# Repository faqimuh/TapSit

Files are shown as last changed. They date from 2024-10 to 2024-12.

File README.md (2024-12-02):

# TapSit
<div align="center">
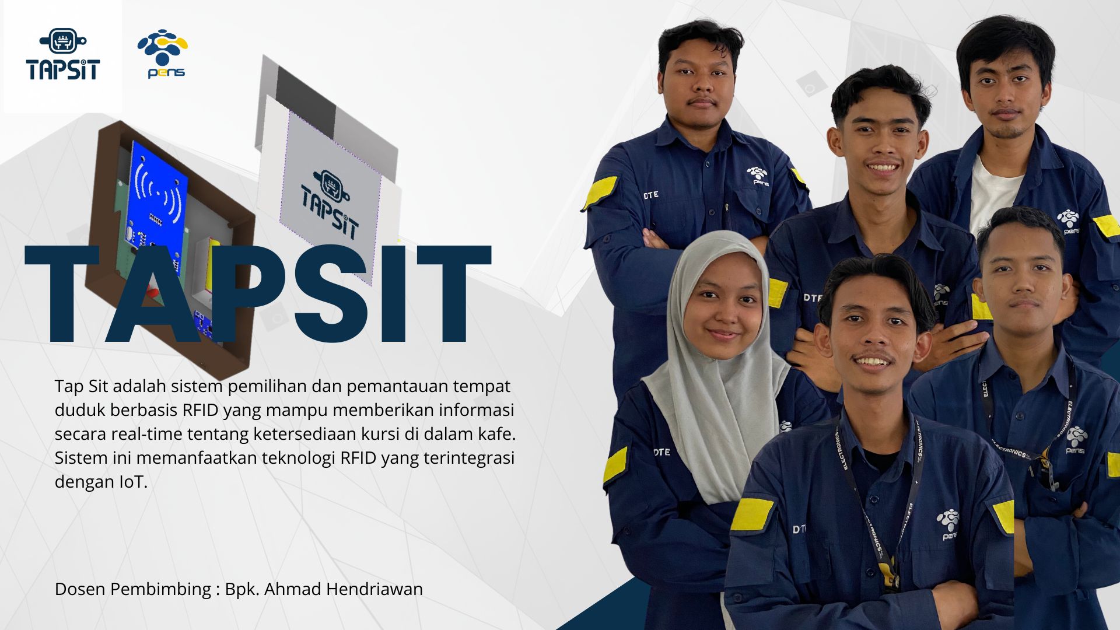
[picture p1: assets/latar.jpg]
latar
  
</div>

# Sistem Pemilihan dan Pemantauan Tempat Duduk Berbasis RFID untuk Optimalisasi Industri F&B
<div align="justify">

Proyek ini bertujuan untuk mengembangkan sistem monitoring otomatis yang memantau ketersediaan tempat duduk di kafe dan restoran, menggunakan mikrokontroler ESP32 dan teknologi RFID. Sistem ini memungkinkan pelanggan untuk memilih meja dengan mengetuk kartu RFID, yang secara instan memperbarui status meja. Data yang dikumpulkan oleh cloud server disimpan dalam database lokal dan ditampilkan di monitor kasir, memungkinkan staf untuk melihat meja yang kosong dan terisi. Dengan demikian, sistem ini meningkatkan kenyamanan pelanggan dan efisiensi operasional, serta mengurangi waktu tunggu dan kesalahan.
[Slide Presentasi TapSit](https://www.canva.com/design/DAGSyjQpQgQ/xJnBZW7nx27bsGf2SDqeiA/edit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)
</div>

`IOT DAN JARINGAN SENSOR - PROGRAM STUDI TEKNIK ELEKTRONIKA - POLITEKNIK ELEKTRONIKA NEGERI SURABAYA`

`DOSEN PENGAMPU : Akhmad Hendriawan ST, MT`
`NIP. 197501272002121003`

## Manfaat
* Mengoptimalkan Pengelolaan Tempat Duduk
* Mengurangi Waktu Tunggu Pelanggan
* Meningkatkan Efisiensi Operasional
* Meningkatkan Kepuasan Pelanggan
* Mengurangi Kesalahan dalam Pengelolaan Tempat Duduk
* Memudahkan Rotasi Pelanggan
* Peningkatan Citra Modern dan Teknologi

## Keunggulan
* Pemantauan Real-time
* Otomatisasi Berbasis IoT
* Modular dan Skalabel
* Kompatibilitas dengan Infrastruktur Jaringan Lokal
* Visualisasi yang Jelas untuk Staf
* Penggunaan Teknologi RFID yang Cepat dan Aman
* Fleksibilitas Protokol Komunikasi

## Development Plan
### Tahun 1
* Monitoring kursi kosong dalam waktu nyata.
* Akses ke platform pemantauan tempat duduk berbasis cloud
* Notifikasi kursi kosong dalam waktu nyata.
* Laporan penggunaan kursi bulanan.
* Dukungan perangkat keras untuk 10 unit pembaca RFID.
### Tahun 2
* Pemantauan multi-lokasi (hingga 3 cabang).
* Laporan penggunaan kursi mingguan dan bulanan.
* Integrasi dengan aplikasi reservasi pihak ketiga.
* Dukungan perangkat keras untuk 30 unit pembaca RFID.
### Tahun 3
* Analitik lanjutan dan laporan custom sesuai permintaan.
* Dukungan pemantauan untuk hingga 10 lokasi.
* Sistem pemesanan kursi langsung untuk pelanggan melalui aplikasi mobile.
* Dukungan perangkat keras untuk 50 unit pembaca RFID.

## Teammates
<div align="center">

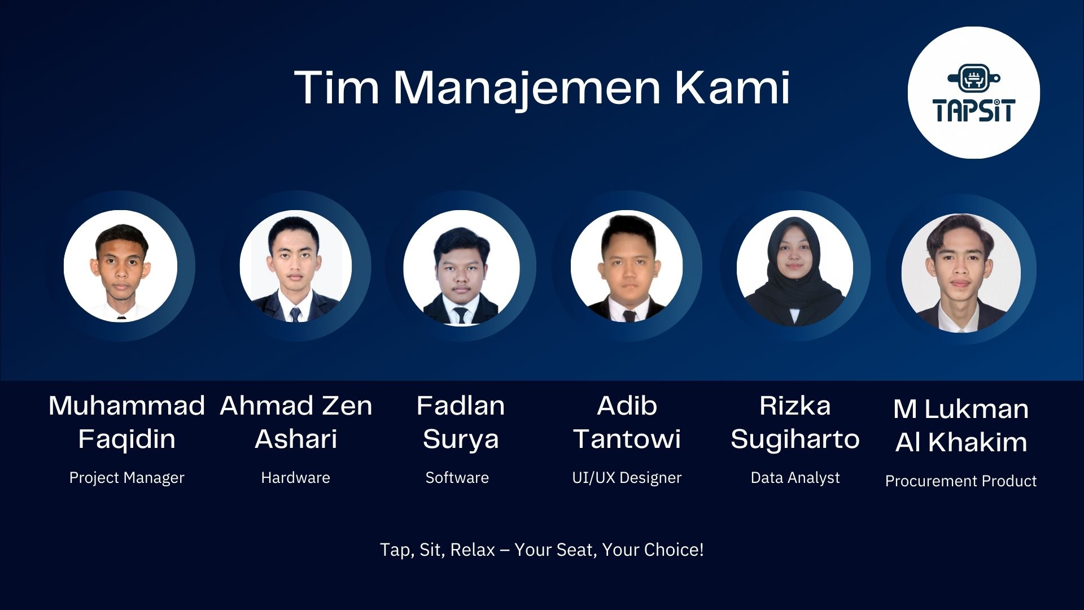
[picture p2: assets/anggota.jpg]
  

| No. | Nama | NRP | Pembagian Tugas | GitHub |
| :--:| :---:| :---:| :---:| :---: |
| 1 | Muhammad Faqidin | 2122600013 | Project Manager, Publikasi melalui Github | [GitHub](https://github.com/faqimuh) |
| 2 | Ahmad Zen Ashari | 2122600009 | Hardware, Desain Skematik dan Hardware, Publikasi melalui Github| [GitHub](https://github.com/ahmadzenashari) |
| 3 | Fadlan Surya | 2122600024 | Software, Mengatur Koneksi Hardware ke Broker, Publikasi melalui Github | [GitHub](https://github.com/fadlansuryanindita) |
| 4 | Adib Tantowi | 2122600001 | UI/UX Designer, Membuat tampilan Web Server, Publikasi melalui Github | [GitHub](https://github.com/AdibTantowi) |
| 5 | Rizka Sugiharto | 2122600008 | Data Analyst, Mengambil data dari Broker ke DataBase, Publikasi melalui Github | [GitHub](https://github.com/Rizka-sgh) |
| 6 | M Lukman Al Khakim  | 2122600010 | Procurement Product, Proses Perakitan dan Soldering, Publikasi melalui Github | [GitHub](https://github.com/2122600010-M-Lukman-Alkhakim) |

</div>

# Daftar Isi
- [Desain Produk](#Desain-Produk)
- [Diagram Arsitektur Sistem](#Diagram-Arsitektur-Sistem)
- [Hardware](#Hardware)
    * [Rangkaian Skematik](#Rangkaian-Skematik)
    * [Pin I/O](#Pinout)
    * [Layout PCB](#Layout-PCB)
- [Software](#Software)
  * [Aktifasi SSL/TLS di Broker HiveMQ CLoud](MQTT/MQTT.md)
  * [Membuat Cloud di AWS Console (EC2)](Cloud/VPS.md)
  * [Koneksi Broker dengan Database Menggunakan Node-Red](Database/progres.md)
- [Rincian Biaya](#Rincian-Biaya)

# Desain Produk

<div align="center">

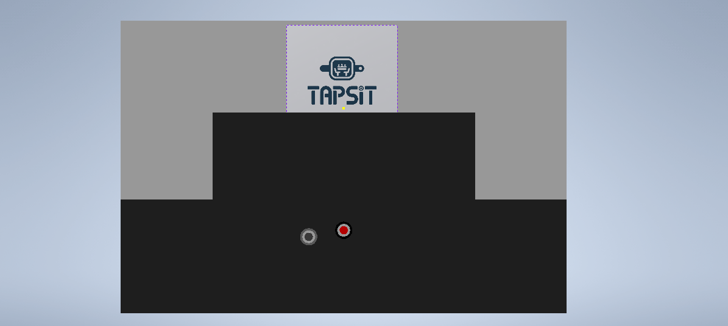
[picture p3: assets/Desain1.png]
Tampilan Produk 0
 
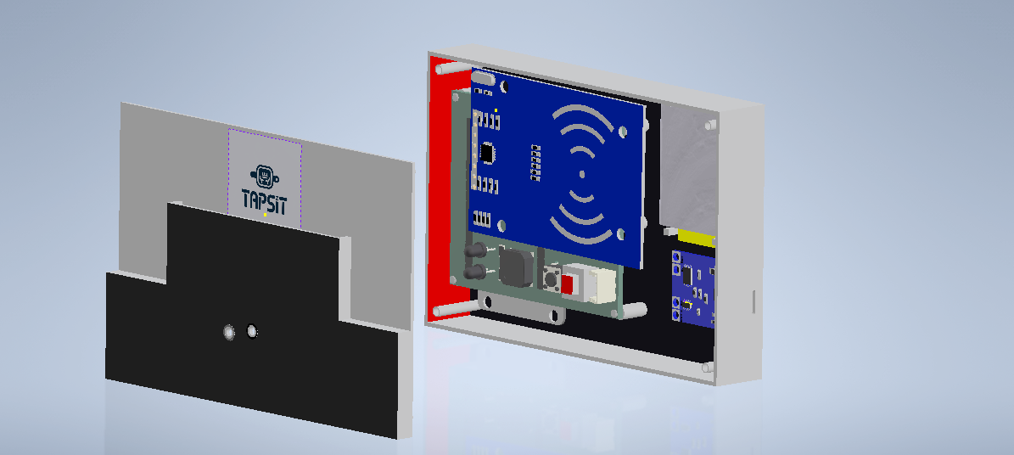
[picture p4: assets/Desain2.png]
Tampilan Produk 1
 
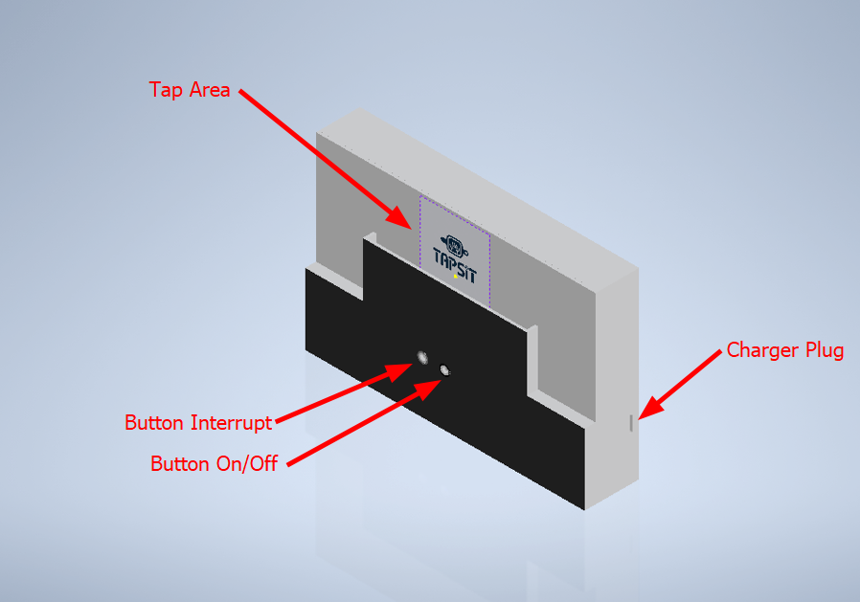
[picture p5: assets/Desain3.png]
Tampilan Produk 2
 

[def0]: /assets/Desain1.png
[def1]: /assets/Desain2.png
[def2]: /assets/Desain3.png
[Download File 3D](https://www.thingiverse.com/thing:6816870) <br>
[File 3D](https://github.com/faqimuh/TapSit/tree/main/Hardware%20Development/Desain3D)
</div>

## Uploud Casing di thingivers
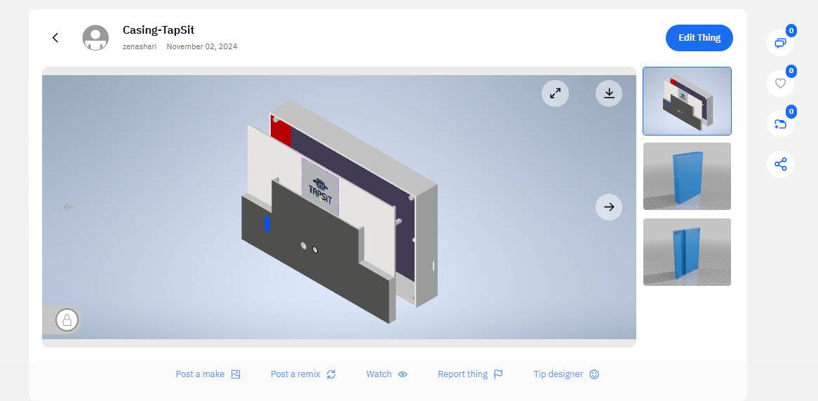
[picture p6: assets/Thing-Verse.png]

<div align="center">

https://www.thingiverse.com/thing:6816870
</div>

## Diagram Block
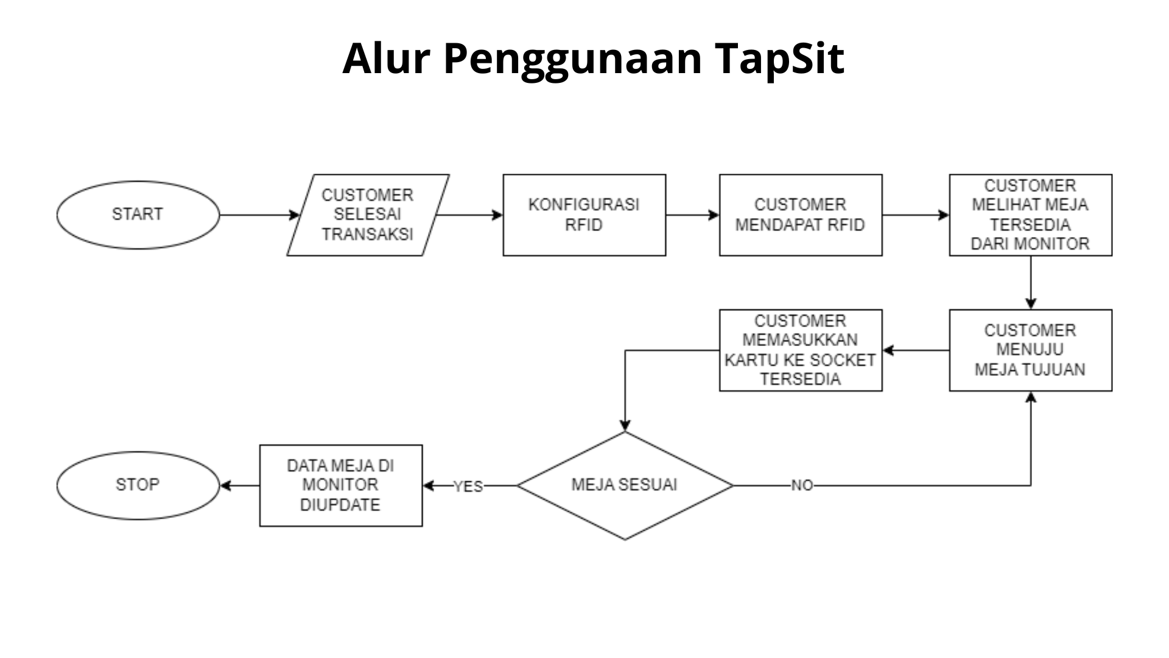
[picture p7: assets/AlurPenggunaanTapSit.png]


# Diagram Arsitektur Sistem

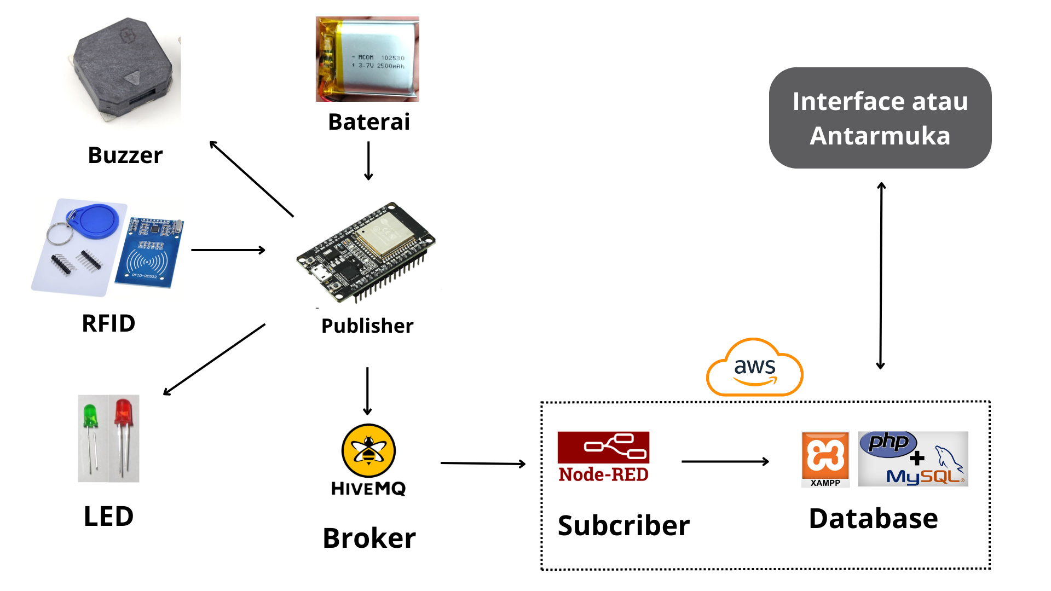
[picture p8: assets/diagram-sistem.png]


# Hardware
## Rangkaian Skematik
<div align = center>
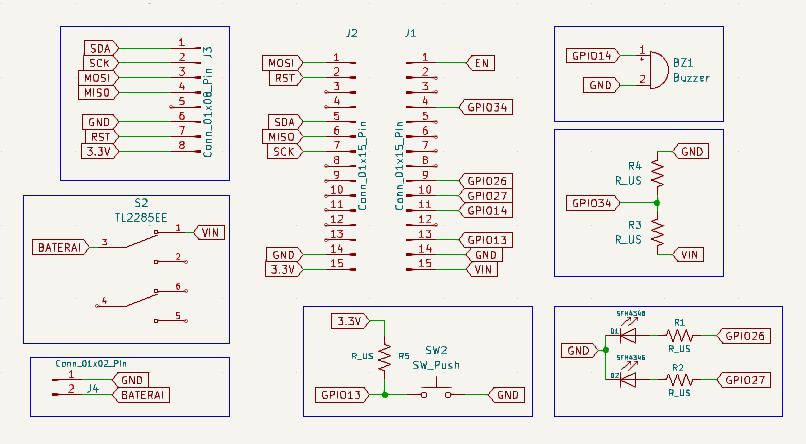
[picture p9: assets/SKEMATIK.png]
Skematik

</div>

 ## Layout PCB
 <div align = center>
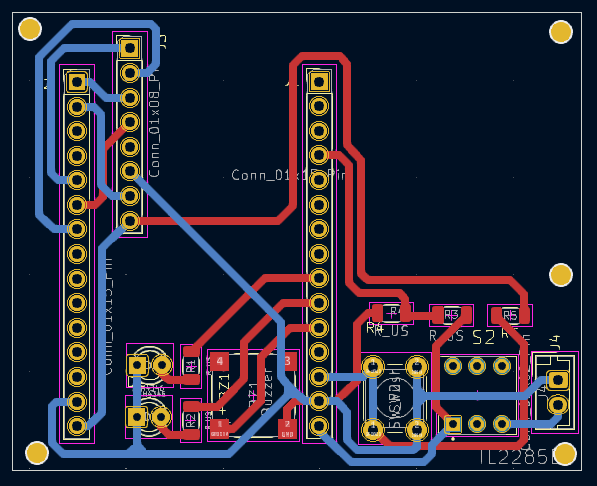
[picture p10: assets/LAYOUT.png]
Layout
  

<p> Menggunakan PCB 2 Layer </p>
<a href="https://github.com/faqimuh/TapSit/tree/main/Hardware%20Development/LayoutPCB">FILE PCB</a>
</div>

  ## Pinout yang Dipakai

Pin GPIO34 | untuk data input baterai<br>
Pin GPIO26 | untuk indikator LED<br>
Pin GPIO27 | untuk indikator LED<br>
Pin GPIO13 | untuk input interrupt<br>
Pin GPIO14 | untuk output buzzer<br>
Pin MISO   | untuk RFID <br>
Pin MOSI   | untuk RFID<br>
Pin SCK    | untuk RFID<br>
Pin SDA    | untuk RFID<br>
Pin RST    | untuk RFID<br>
Pin 3,3V   | untuk input tegangan<br>
Pin GND    | untuk ground<br>

# Software
Selamat datang di proyek ini. Berikut adalah beberapa panduan yang mungkin Anda butuhkan:
- [Aktifasi SSL/TLS di Broker HiveMQ CLoud](MQTT/MQTT.md)
- [Membuat Cloud di AWS Console (EC2)](Cloud/VPS.md)
- [Koneksi Broker dengan Database Menggunakan Node-Red](Database/progres.md)

# Rincian Biaya

| No  | Item | Jumlah | Harga | Total |Link|
|-----|---|---|---|---|-----|
| 1 | ESP32 Devkitc 32D | 1 | 66.900  | 66.900  |[Buy](https://s.shopee.co.id/g7zNegvfe) |
| 2 | Buzzer SMD 8530 3V | 1 | 4.000 | 4.000 |[Buy](https://www.tokopedia.com/marnov/buzzer-smd-8530-3v-16r-8-5-3mm-piezo-mini-aktif-pasif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) |
| 3 | LED SMD 1206 | 2 | 140 | 280 |[Buy](https://tokopedia.link/4pipX6fPrNb)|
| 4 | RFID MRFC 522 | 1 | 14.000  | 14.000  |[Buy](https://s.shopee.co.id/sIaWPa9R) |
| 5 | Resistor SMD 1206 | 3 | 150 | 450 |[Buy](https://tokopedia.link/CMivhgmPrNb) |
| 6 | Etching Papan PCB | 1 | 8.000 | 8.000 | |
| 7 | 3D print casing | 1 | 20.000  | 20.000  | |
| 8 | TP4056 1A 5V Lithium | 1 | 4.000 | 4.000 |[Buy](https://www.tokopedia.com/isee/tp4056-1a-5v-lithium-lipo-18650-battery-charging-usb-type-c-proteksi) |
| 9 | Lithium 2500mah 3.7V | 1 | 37.000  | 37.000  |[Buy](https://id.shp.ee/LSUCxvz) |
| | | | **TOTAL** | 154.630 |

# Tampilan UI/UX
<div align="center">
  <h3><span style="color:#0078D7;">Tampilan Index</span></h3>
   <p><i>Menampilkan informasi ketersediaan meja secara real-time, membantu pengguna mengetahui meja yang kosong atau terisi.</i></p>
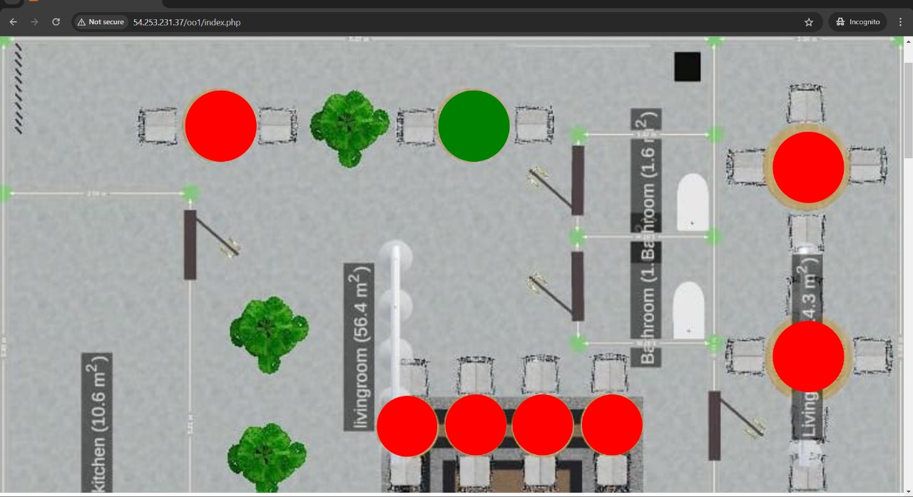
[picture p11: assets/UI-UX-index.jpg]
Index
  
</div>

<div align="center">
  <h3>Tampilan Login </h3>
  <p><i>Halaman login untuk mengamankan akses ke web admin, dirancang khusus agar hanya karyawan atau pemilik yang dapat masuk .</i></p>
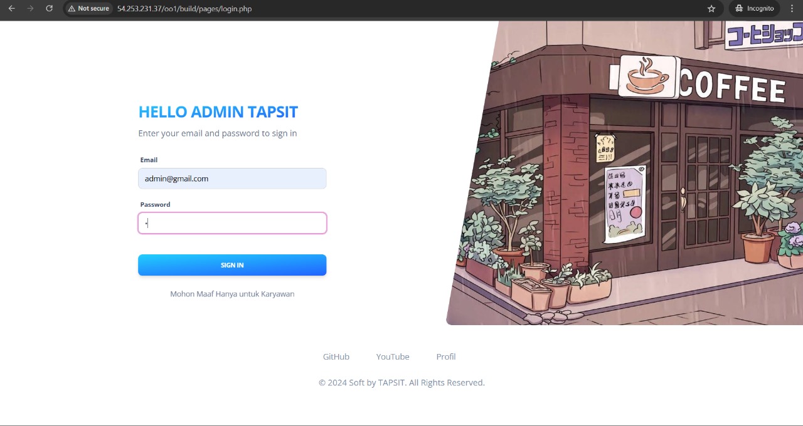
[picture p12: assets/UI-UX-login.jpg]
Login
  
</div>

<div align="center">
  <h3> Tampilan Admin </h3>
  <p><i>
    Tampilan ini dirancang khusus untuk karyawan atau pemilik yang memiliki akses ke halaman admin. Melalui halaman ini, mereka dapat memantau kondisi meja secara real-time, termasuk informasi apakah meja kosong atau terisi, serta melihat status RFID di setiap meja. Selain itu, halaman ini terdapat pengecekan tingkat baterai alat RFID, yang dikategorikan dalam tiga kondisi: aman, hampir habis, atau habis, guna memastikan perangkat berfungsi dengan optimal. Admin juga memiliki kemampuan untuk mengganti password login sebagai langkah menjaga keamanan akses sistem.
  </i></p>
  </i></p>
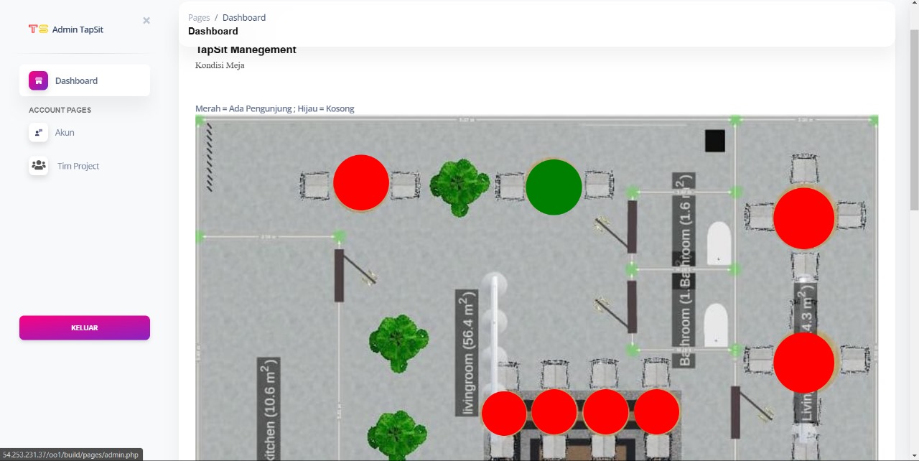
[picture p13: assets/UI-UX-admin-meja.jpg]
Admin - Kondisi Meja
  
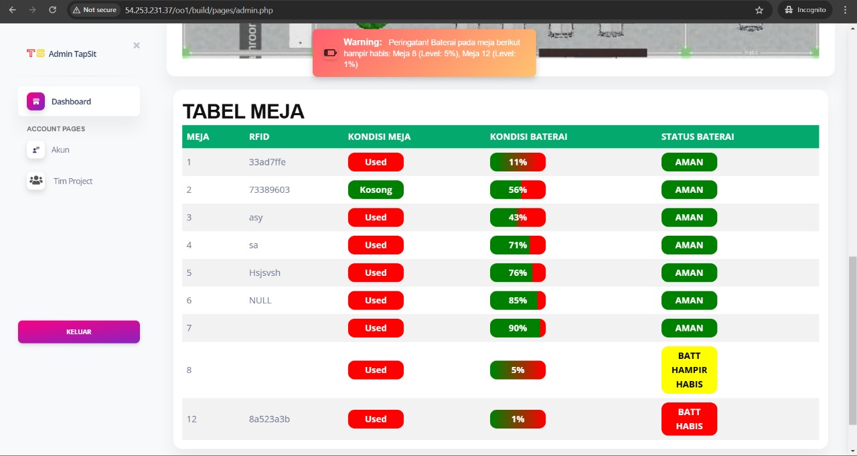
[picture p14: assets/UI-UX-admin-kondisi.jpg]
Admin - Kondisi Alat
  
  <a href="https://github.com/faqimuh/TapSit/tree/main/Interface%20UI/UX">FILE UI-UX</a>
</div>

# Cara Penggunaan 

https://github.com/user-attachments/assets/884f3dd7-7e4f-4ce1-bf2d-9252606a5dd6

1. Pastikan perangkat dalam kondisi menyala dan telah berhasil terhubung dengan jaringan Wi-Fi untuk memastikan kelancaran proses komunikasi data.
2. Pada tampilan web server, sistem akan menampilkan status setiap meja; meja yang belum terisi akan ditandai dengan warna hijau, sementara meja yang telah terisi akan ditandai dengan warna merah, memungkinkan pemantauan kondisi secara visual.
3. Tempelkan kartu RFID yang sudah terdaftar pada perangkat untuk mengaktifkan proses pengenalan identitas melalui sensor.
4. Data dari kartu RFID yang ditempelkan akan secara otomatis dikirim dan disimpan dalam database untuk tujuan pencatatan dan pemantauan.
5. Pada perangkat atau meja yang sama, sistem database hanya akan memperbarui informasi terkait kondisi terakhir RFID serta status pemantauan baterai untuk efisiensi penyimpanan dan pemrosesan data.
6. Setelah kartu RFID berhasil ditempelkan pada perangkat, tampilan pada web server akan secara otomatis diperbarui, menunjukkan bahwa meja tersebut telah terisi, berkat registrasi yang telah terjadi melalui perangkat.

Untuk memberikan gambaran yang lebih jelas, video ini akan menunjukkan seluruh proses, mulai dari pengaktifan hingga penggunaan alat dalam berbagai kondisi, sehingga Anda bisa memahami manfaat dan efisiensi alat kami yang dapat diakses pada link [VIDIO IKLAN](https://youtu.be/MPJk97POcxs?si=4I_-UE-o9XQQt0bo)

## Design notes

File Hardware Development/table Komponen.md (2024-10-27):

# Perbandingan Komponen

| No  | Komponen | Alternatif | Fitur Utama | Keunggulan | Alasan Pemilihan |
|-----|---|---|---|---|---|
| 1 | ESP32 Devkitc 32D | ESP8266 | Wi-Fi, Bluetooth | Konsumsi daya rendah, fitur lengkap | **ESP32 dipilih** karena memiliki fitur lebih lengkap (Wi-Fi, Bluetooth, dan GPIO 34 pin) serta konsumsi daya lebih rendah. Sementara itu, ESP8266 hanya mendukung Wi-Fi dengan GPIO lebih sedikit. |
| 2 | Buzzer SMD 8530 3V | Piezo Speaker | Indikasi suara | Biaya murah, mudah diimplementasi | **Buzzer** dipilih karena lebih murah dan cukup untuk memberikan umpan balik suara sederhana. Piezo speaker lebih mahal dan tidak diperlukan untuk fungsi dasar ini. |
| 3 | LED SMD 1206 | LED 5mm | Efisiensi energi, ukuran kecil | Konsumsi daya rendah | **LED SMD** dipilih karena ukurannya lebih kecil dan lebih efisien daripada LED 5mm, cocok untuk aplikasi hemat energi. |
| 4 | RFID MRFC 522 | PN532 RFID | Komunikasi RFID 13.56 MHz | Biaya rendah, ukuran kecil | **MRFC 522** dipilih karena ekonomis dan cukup untuk aplikasi sederhana. PN532 memiliki fitur lebih banyak tetapi tidak dibutuhkan dan harganya lebih tinggi. |
| 5 | Resistor SMD 1206 | Resistor Through Hole | Komponen pasif | Ukuran kecil, stabilitas tinggi | **Resistor SMD** dipilih karena lebih kecil dan sesuai untuk produksi PCB, menghemat ruang dibanding resistor through-hole yang lebih besar dan kurang efisien. |
| 6 | Etching Papan PCB | Veroboard | Desain rangkaian tetap | Struktur stabil | **Papan PCB** dipilih untuk instalasi permanen yang rapi dan stabil, sedangkan Veroboard lebih cocok untuk prototyping. |
| 7 | 3D Print Casing | Kotak Plastik | Penyimpanan komponen elektronik | Melindungi dari debu dan air  | **Box hasil 3D printing** dipilih karena memberikan perlindungan lebih baik terhadap debu dan air dibandingkan kotak plastik biasa. |
| 8 | Modul Battery TP4056 1A 5V Lithium | NiMH Rechargeable | Rechargeable, kapasitas tinggi | Ringan, efisiensi daya tinggi | **Modul Battery TP4056** dipilih karena lebih efisien dan ringan dibandingkan NiMH, yang lebih berat dan kurang efisien untuk aplikasi dengan pengisian ulang berulang. |
| 9 | Lithium 2500mAh 3.7V | NiMH Rechargeable | Kapasitas tinggi, ringan | Daya tahan lama, efisiensi tinggi | **Baterai Lithium 2500mAh 3.7V** dipilih karena bobotnya ringan, kapasitas tinggi, dan efisiensi lebih baik. Dibandingkan NiMH, Lithium memiliki kecepatan pengisian lebih cepat, self-discharge rendah, dan lebih sesuai untuk aplikasi jangka panjang. |

## Komponen
### 1. Resistor
Pembagi Tegangan:<br>
𝑉𝑜𝑢𝑡 = 𝑉𝑖𝑛 × 𝑅2 / (𝑅1 + 𝑅2)<br>
    Diketahui:<br>
                𝑉𝑖𝑛 = 12V<br>
                𝑉𝑜𝑢𝑡 = 3V<br>
                𝑅1 = 10KΩ<br>
𝑅2 = (𝑉𝑜𝑢𝑡 × 𝑅1) / (𝑉𝑖𝑛 − 𝑉𝑜𝑢𝑡)<br>
𝑅2 = (3V × 10KΩ) / (12V − 3V)<br>
𝑅2 = 3.33KΩ<br>
Hasil: Untuk mendapatkan tegangan output 3V dari sumber 12V, dengan R1 = 10KΩ, diperlukan R2 = 3.33KΩ.
<br>
Note :<br>
Untuk menurunkan Tegangan, Pembagi tegangan memungkinkan penurunan tegangan dari sumber yang lebih tinggi ke nilai yang lebih rendah, sesuai dengan kebutuhan komponen di rangkaian.<br>
<br>
### 2. Battery
Diketahui:<br>
Arus max beban = 200mA<br>
Waktu pemakaian = 12 jam<br>
Kapasitas Baterai = Arus Beban × Waktu Pemakaian<br>
Kapasitas = 200 mA × 12 jam = 2400 mAh<br>
Waktu Pengisian Baterai:<br>
Waktu Pengisian = Kapasitas Baterai / Arus Pengisian<br>
Waktu = 2500 mAh / 1000 mA × 1/0.8 = 3.125 jam<br>
Perkiraan Lama Pemakaian:<br>
Lama Pemakaian = Kapasitas Baterai / Arus Beban<br>
Lama = 2500 mAh / 200 mA = 12.5 jam<br>
Note :<br>
Dengan Menggunakan baterai berkapasitas besar seperti 2500mAh atau 3000mAh juga dapat meningkatkan efisiensi pengisian. Modul pengisian seperti TP4056 akan bekerja lebih optimal ketika dipasangkan dengan baterai berkapasitas lebih besar karena pengisian akan berlangsung lebih lama pada arus yang lebih tinggi, mengurangi kerugian daya akibat pengisian berulang kali.

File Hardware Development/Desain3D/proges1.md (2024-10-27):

<div align="center">
  <h1>Desain 3D Produk</h1>
  <h2>Tampilan 3D PCB</h2>
  
  <!-- Gambar PCB -->
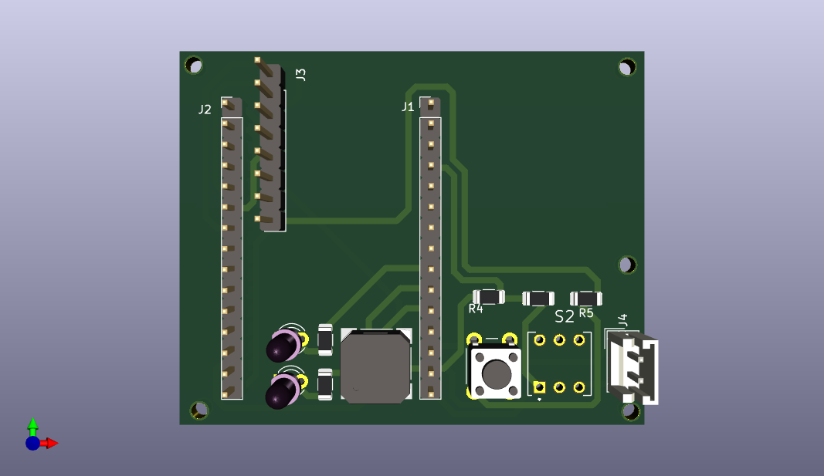
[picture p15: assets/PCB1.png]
Tampilan Produk 1
    
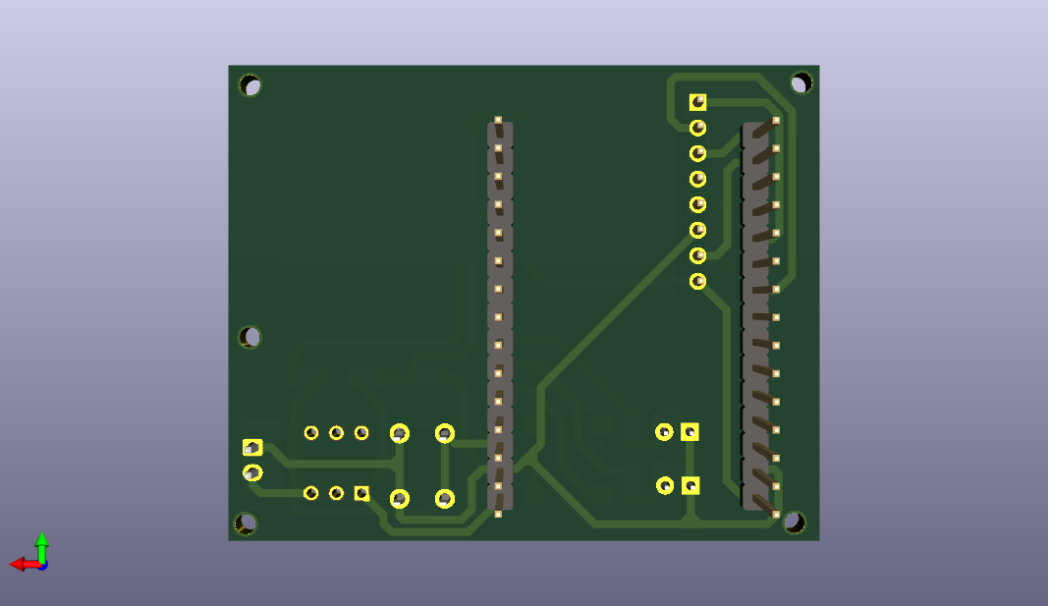
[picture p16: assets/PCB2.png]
Tampilan Produk 2
   

  <!-- Gambar yang menjadi tautan ke video -->
 <h2> Tampilan Produk </h2>
<video controls src="../../assets/produk.mp4" title="Title"></video>

 <h3>Tampak Depan</h3>

 Tampilan Produk 3

  <h3>Tampak Samping</h3>
 
 Tampilan Produk 4

  <h3> Keterangan Bagian</h3>
 
 Tampilan Produk 5

</div>

[def1]: /assets/PCB1.png
[def2]: /assets/PCB2.png
[def3]: /assets/Desain1.png
[def4]: /assets/Desain2.png
[def5]: /assets/Desain3.png

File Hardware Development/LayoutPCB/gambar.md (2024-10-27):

<div align="center">
  <h1> Layout PCB </h1>
  
  Tampilan Produk 1 
</div>

[def1]: /assets/LAYOUT.png

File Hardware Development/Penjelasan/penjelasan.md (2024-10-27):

<div style="background-color: #2e2e2e; padding: 10px; border-radius: 5px; color: white;">
  <h1>WORKSHOP MIKROKONTROLLER - PROGRAM STUDI TEKNIK ELEKTRONIKA - POLITEKNIK ELEKTRONIKA NEGERI SURABAYA</h1>
  <p>DOSEN PENGAMPU : Akhmad Hendriawan ST, MT <br/> NIP. 197501272002121003 <br/>Dibuat Oleh : Ahmad Zen Ashari<br/> NRP : 2122600009</p>
</div>

<div align = center>
 <h2>Penjelasan Skematik</h2>

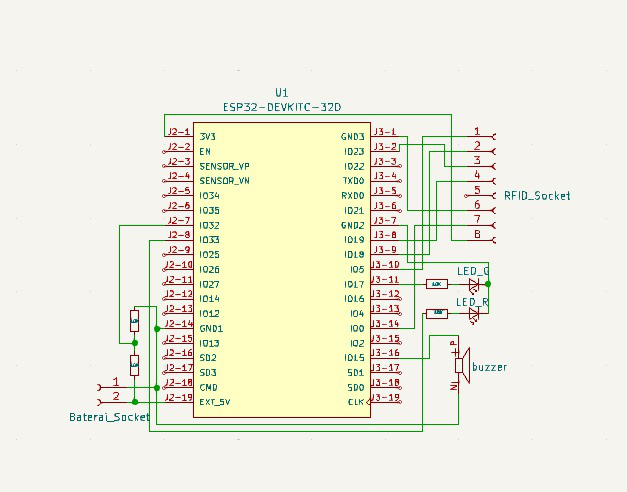
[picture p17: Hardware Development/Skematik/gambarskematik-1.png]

</div>

<div align=center>
<h3> Daftar pin yang digunakan </h3>
<!-- Tabel dengan CSS di file Markdown -->
<div class="table-container">
    <table>
        <thead>
            <tr>
                <th>No</th>
                <th>Pin GPIO Ke- </th>
                <th>Alasan</th>
                <th>Fungsi</th>
            </tr>
        </thead>
        <tbody>
            <tr>
                <td>1</td>
                <td>32</td>
                <td>Aman untuk I/O</td>
                <td>Input info daya baterai</td>
            </tr>
            <tr>
                <td>2</td>
                <td>15</td>
                <td>Aman untuk I/O</td>
                <td>Output ke buzzer</td>
            </tr>
            <tr>
                <td>3</td>
                <td>33</td>
                <td>Aman untuk I/O</td>
                <td>Output ke LED_G</td>
            </tr>
            <tr>
                <td>4</td>
                <td>17</td>
                <td>Aman untuk I/O</td>
                <td>Output ke LED_R</td>
            </tr>
         </tbody>
    </table>

<p>Untuk file skematik, dapat diunduh <a href="https://drive.google.com/file/d/1diomlFyTaUs_eFDkaGRLsYESl7vDo8c1/view?usp=sharing">di sini</a>.</p>

<div align = center>
 <h2>Penjelasan Layout</h2>

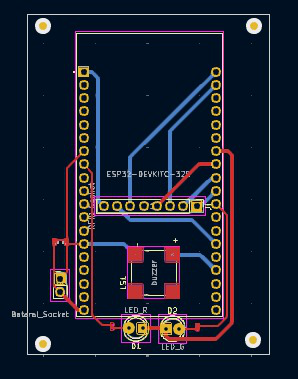
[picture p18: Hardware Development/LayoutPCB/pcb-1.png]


</div>

<p> Menggunakan PCB 2 Layer <br>Ukuran jalur 0,75mm dan 0,3mm</p>

<p>Untuk file PCB, dapat diunduh <a href="https://drive.google.com/file/d/1fTUtGnzqFyHy10sOkZaSZF4weKkYOswV/view?usp=sharing">di sini</a>.</p>

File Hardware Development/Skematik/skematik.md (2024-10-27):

<div align="center">
  <h1> Layout PCB </h1>
  
  Tampilan Produk 1 

</div>

[def1]: /assets/SKEMATIK.png

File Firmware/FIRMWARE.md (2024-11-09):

# TAPSIT FIRMWARE
<div align="justify">
Firmware diprogram dengan menggunakan software PLATFORM IO pada Visual Studio Code. Program menggunakan framework milik arduino dengan tujuan mempermudah penggunaan library pada sistem.
</div>

## LIBRARY

Library yang kami gunakan untuk memprogram firware dari system kami meliputi sebagai berikut.  

#### 1. <WiFi.h> dan <WiFiManager.h>
<div align="justify">
        Library `wifi`  digunakan untuk menghubungkan system hardware dengan koneksi internet dengan protokol wifi atan wlan (wireless lan). Untuk melakukan konfigurasi tersebut, digunakanlah  library `wifi manager`. Salah satu Kelebihan dari library wifi manager ada pada fitur penyimpanan konfigurasi wifi yang telah disetting. Library `wifi manager` juga kami setting secara `advance` untuk memberikan input parameter tambahan yang dicustom untuk memberikan suatu variable untuk device tersebut.  Pada library `wifi manager` yang disetting advance juga dapat menambahkan button untuk melakukan reset konfigurasi dari koneksi wifi dan juga dapat membuat suatu algoritma timeout ketika wifi tidak dapat tersambung.

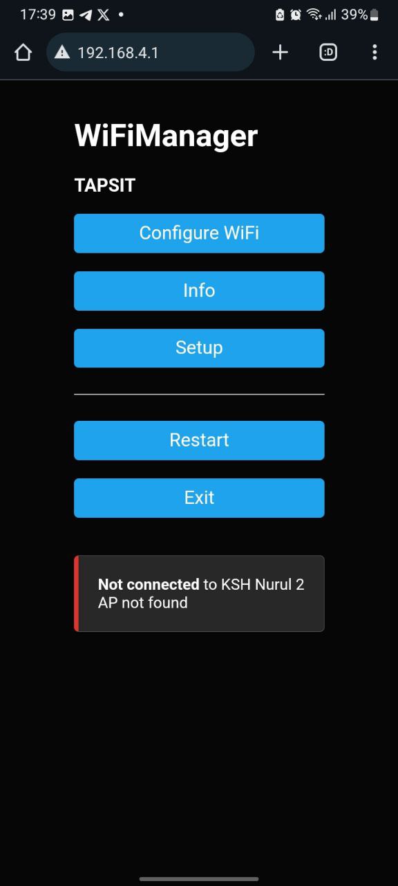
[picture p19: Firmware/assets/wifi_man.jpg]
Layout


</div>

#### 2. <PubSubClient.h>
<div align="justify">
        Library `PubSubClient` adalah library Arduino yang digunakan untuk mengimplementasikan komunikasi **Message Queue Telemetry Transport* (MQTT) pada microcontroller seperti ESP32 atau ESP8266. `MQTT` merupakan protokol komunikasi yang ringan dan banyak digunakan dalam aplikasi *Internet of Things* (IoT) untuk mengirim dan menerima data antara perangkat dan *server* (broker) melalui jaringan internet.
</div>

#### 3. <Preferences.h>
<div align="justify">
        Library `Preferences` di ESP32 memungkinkan penyimpanan data secara non-volatile, sehingga data tetap tersimpan meskipun perangkat dimatikan atau di-restart. Dengan menggunakan `Preferences`, kamu dapat menyimpan berbagai jenis data, seperti string, integer, dan boolean, dengan cara yang mudah dan efisien. Proses dimulai dengan menginisialisasi objek `Preferences` di dalam fungsi `setup()`, kemudian menyimpan data seperti nomor meja atau identitas hardware menggunakan metode `putString()`, `putInt()`, atau metode lainnya sesuai tipe data yang diinginkan. Untuk mengambil data yang telah disimpan, cukup gunakan metode `getString()` atau `getInt()` dengan kunci yang sama yang digunakan saat menyimpan. Selain itu, library ini juga menyediakan fungsi untuk menghapus data yang disimpan jika diperlukan. Semua data yang disimpan berada dalam flash memory ESP32, sehingga tetap dapat diakses setelah perangkat dimatikan. Dalam aplikasi kamu, library `Preferences` digunakan untuk menyimpan data nomor meja atau identitas hardware ESP32 yang didapat dari custom parameter WiFi Manager Advance, memastikan bahwa informasi ini selalu tersedia bahkan setelah perangkat di-restart. Dengan demikian, library `Preferences` sangat cocok digunakan untuk menyimpan informasi penting yang perlu diakses kembali setelah restart, seperti data konfigurasi atau identitas unik dalam aplikasi IoT.
</div>

#### 4. <SPI.h> dan <MFRC522.h>
<div align="justify">
      Library `<SPI.h>` dan `<MFRC522.h>` kami gunakan secara bersamaan untuk mengoperasikan RFID reader MFRC522 dengan mikrokontroler seperti Arduino atau ESP32. Library `<SPI.h>` menyediakan antarmuka untuk komunikasi SPI (Serial Peripheral Interface), yang merupakan protokol yang diperlukan untuk berkomunikasi dengan perangkat seperti MFRC522. Di sisi lain, library `<MFRC522.h>` menyediakan fungsi khusus untuk mengatur dan mengelola operasi RFID, termasuk membaca dan menulis data pada kartu RFID. Penggunaannya dimulai dengan menginisialisasi objek MFRC522 dan mengatur koneksi SPI di dalam fungsi `setup()`. Setelah itu, kami dapat menggunakan berbagai fungsi yang disediakan oleh library ini untuk mendeteksi kartu RFID, membaca informasi dari kartu, atau melakukan operasi lain yang berkaitan dengan RFID. Kombinasi kedua library ini memungkinkan kami untuk mengembangkan aplikasi berbasis RFID yang efektif, seperti sistem akses kontrol atau manajemen inventaris, dengan cara yang sederhana dan intuitif.
</div>
        
#### 5. "esp32-hal-timer.h"
<div align="justify">
        File header `esp32-hal-timer.h` dalam framework Arduino untuk ESP32 digunakan untuk mengelola timer dengan efisien. File ini menyediakan fungsi untuk menginisialisasi dan mengonfigurasi timer dalam mode one-shot dan periodic, serta memungkinkan pengaturan prescaler untuk menentukan kecepatan penghitungannya. Salah satu fitur utamanya adalah kemampuan untuk mengatur interrupt, yang memicu eksekusi kode secara otomatis saat timer mencapai nilai tertentu. Dalam pengaplikasiannya, kami menggunakan timer ini untuk memperbarui  baterai sistem setiap 30 menit. Dengan demikian, `esp32-hal-timer.h` menyederhanakan pengelolaan timer, memungkinkan pengembang untuk membuat aplikasi yang responsif dan terjadwal dengan baik dalam lingkungan IoT.

## ALGORTIMA PROGRAM

        Program ini adalah sistem komunikasi berbasis IoT yang memanfaatkan ESP32 untuk menghubungkan perangkat ke jaringan Wi-Fi dan broker MQTT guna mengirimkan data yang diperoleh dari pembacaan kartu RFID. Pada fungsi setup, inisialisasi dilakukan pada beberapa komponen yang digunakan, seperti koneksi Wi-Fi, modul MQTT, dan sensor RFID, yang masing-masing membutuhkan library tertentu. Wi-Fi dikonfigurasi dengan bantuan `WiFiManager` untuk memudahkan koneksi secara dinamis, tanpa perlu memasukkan kredensial Wi-Fi secara manual pada setiap penggunaan. Hal ini memungkinkan perangkat untuk membuka portal konfigurasi jika koneksi Wi-Fi gagal, sehingga pengguna dapat memasukkan kredensial baru.

        Pada fungsi setup ini, perangkat ESP32 memeriksa apakah sudah ada data `deviceID` yang tersimpan di memori non-volatile `Preferences`. Jika `deviceID` tidak ditemukan, maka perangkat akan menggunakan nilai default. `Preferences` digunakan untuk menyimpan informasi yang dapat diakses kembali ketika perangkat dinyalakan ulang, yang memastikan bahwa pengaturan yang pernah dilakukan oleh pengguna tetap bertahan. Selain itu, pada tahap setup ini, kanal PWM disiapkan untuk buzzer dengan frekuensi dan resolusi tertentu, dan modul RFID diinisialisasi melalui antarmuka SPI, yang memungkinkan pembacaan UID kartu RFID.

        Setelah koneksi Wi-Fi berhasil, perangkat ESP32 menghubungkan diri ke broker MQTT. Program menggunakan library `PubSubClient` untuk mengelola komunikasi dengan server MQTT. Pengaturan koneksi ke broker MQTT dilakukan dengan mendefinisikan server, port, username, dan password untuk mengautentikasi perangkat saat menghubungkan diri ke broker. Fungsi `reconnect()` digunakan untuk menangani skenario ketika koneksi ke broker terputus. Dalam fungsi ini, perangkat akan terus berusaha menghubungkan diri ke broker sampai koneksi berhasil, memastikan aliran data tetap lancar.

        Program ini juga menggunakan timer untuk memicu fungsi interrupt setiap 10 detik guna mengukur level baterai pada perangkat. Pada fungsi interrupt `onTimer()`, perangkat membaca level baterai dengan mengukur nilai analog dari pin tertentu dan mengonversinya menjadi persentase untuk memudahkan interpretasi. Nilai persentase ini kemudian disimpan dalam variabel `batt`, yang akan dikirim bersama data lainnya melalui MQTT. Penggunaan timer dengan fungsi interrupt memungkinkan pembacaan level baterai secara periodik tanpa mengganggu operasi utama dalam loop.

        Pada loop utama, program memverifikasi apakah perangkat masih terhubung dengan broker MQTT. Jika koneksi terputus, fungsi `reconnect()` dipanggil kembali untuk memperbarui koneksi. Program juga memiliki fungsi `checkButton()` yang memeriksa apakah tombol konfigurasi pada perangkat ditekan. Jika tombol ditekan dan ditahan selama 3 detik, konfigurasi Wi-Fi pada perangkat akan di-reset, sehingga perangkat dapat memulai ulang koneksi Wi-Fi dengan mengaktifkan kembali portal konfigurasi. Ini memungkinkan pengguna untuk mengonfigurasi ulang koneksi Wi-Fi sesuai kebutuhan.

        Ketika kartu RFID terdeteksi, perangkat membaca UID kartu dan menyusunnya dalam string `msg` bersama dengan data `deviceID` dan level baterai. Data ini diformat dan dikirim ke broker MQTT melalui topik "tapsit". Setelah pesan berhasil dikirim, LED dan buzzer memberikan indikasi kepada pengguna dengan menyalakan LED merah dan mengaktifkan bunyi buzzer. Fungsi ini diatur dengan menyesuaikan frekuensi PWM pada buzzer, memberikan notifikasi bahwa kartu telah berhasil terbaca dan data telah dikirim.

        Pada fungsi `saveParamCallback()`, program menyimpan nilai `deviceID` yang diperoleh dari input pengguna ke dalam `Preferences`. Fungsi ini dipanggil ketika pengguna menyimpan pengaturan di portal konfigurasi. Dengan menyimpan `deviceID` dalam `Preferences`, perangkat akan tetap memiliki informasi ini setelah dinyalakan ulang, memungkinkan akses berkelanjutan ke data yang tersimpan. Proses ini memastikan bahwa konfigurasi perangkat dapat dipertahankan tanpa perlu diatur ulang secara manual setiap kali perangkat dimatikan atau mengalami reset. Pada proram ini data yang disimpan di preferences merupakan identitas dari device yaitu nomor device dimana akan ditempatkan di suatu meja.

Video Title

</div>

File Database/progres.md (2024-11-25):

## Node-Red
Node-Red adalah alat pemrograman visual berbasis flow yang memungkinkan penggunanya untuk menyusun alur kerja aplikasi dengan cara menghubungkan node dalam antarmuka yang sederhana. Node-Red sering digunakan untuk integrasi data dalam IoT karena dapat menghubungkan berbagai perangkat, API, dan layanan dengan mudah. Setiap node di Node-Red memiliki fungsi tertentu, seperti menerima data dari perangkat, memprosesnya, dan mengirimkannya ke tujuan yang diinginkan.

Node-Red mendukung berbagai protokol dan layanan seperti MQTT, HTTP, WebSocket, dan banyak lainnya, sehingga memudahkan integrasi dengan broker MQTT dan database MySQL.

Jika kamu menggunakan Node-Red, berikut langkah-langkahnya:
### 1. Cara Menggunakan Node-Red untuk Mengambil Data dari Broker MQTT
Brikut langkah-langkah untuk mengambil data dari broker MQTT menggunakan Node-Red:
#### Instalasi Node MQTT di Node-Red
   * Buka Node-Red dashboard.
   * Klik ikon menu (biasanya di kiri atas) > Manage Palette > Install.
   * Cari mqtt dan pastikan node MQTT sudah terinstal.
#### Tambahkan Node MQTT di Alur Node-Red
   * Di workspace Node-Red, pilih MQTT in dari kategori input dan tarik node ini ke dalam alur kerja.
   * Node ini berfungsi untuk menerima data dari topik tertentu di broker MQTT.
#### Konfigurasi Pengaturan MQTT
* Klik dua kali pada node MQTT in untuk mengatur koneksi ke broker MQTT:
    - Server: Masukkan alamat broker, misalnya your_hivemq_cluster_host.
    - Port: Masukkan 8883 jika broker menggunakan TLS, atau 1883 jika tidak.
    - Client ID: Berikan Client ID unik.
    - Username dan Password: Masukkan username dan password sesuai konfigurasi di broker.
* Topik: Masukkan topik yang akan dipantau (misalnya sensor/data).
* QoS: Atur ke 0, 1, atau 2 tergantung pada tingkat keandalan yang diinginkan (QoS 2 adalah yang paling andal).
#### Melihat Data di Node-Red
* Hubungkan node MQTT in ke Debug node untuk melihat data yang diterima.
* Klik Deploy untuk mulai menjalankan alur kerja. Data yang diterima dari broker MQTT akan muncul di panel debug.

### 2.  Cara Mengirim Data dari Broker MQTT ke MySQL dengan Node-Red
Untuk mengirim data yang diterima dari broker MQTT ke database MySQL, ikuti langkah-langkah berikut:

#### Instal Node MySQL di Node-Red
* Buka Manage Palette di Node-Red dan cari node-red-node-mysql.
* Instal node MySQL jika belum tersedia.
#### Tambahkan Node MySQL ke Alur Node-Red
* Pilih node MySQL dari kategori storage dan tarik ke dalam alur kerja.
* Node ini berfungsi untuk memasukkan data ke dalam database MySQL.
#### Konfigurasi Pengaturan MySQL
* Klik dua kali pada node MySQL untuk mengatur koneksi ke database:
    - Host: Masukkan alamat server MySQL (misalnya localhost atau alamat IP server MySQL).
    - User dan Password: Masukkan username dan password MySQL.
    - Database: Masukkan nama database yang akan digunakan.
* Klik Add untuk menyimpan konfigurasi database.
#### Buat Query SQL untuk Menyimpan Data
* Sebelum mengirim data ke MySQL, buat tabel di database sesuai data yang akan disimpan. Misalnya, jika data dari broker adalah sensor_id, temperature, dan humidity, buat tabel dengan kolom ini.
* Dalam node MySQL, masukkan query SQL untuk memasukkan data, misalnya:
function creat database

Di mana ? akan digantikan oleh data dari alur kerja Node-Red.

#### Hubungkan Node MQTT dengan Node MySQL
* Hubungkan node MQTT in (yang menerima data dari broker) ke node MySQL.
* Tambahkan node function di antara node MQTT in dan MySQL untuk memformat data yang diterima agar sesuai dengan query SQL. Contoh kode dalam node function:
#### Jalankan dan Uji Alur Kerja
* Klik Deploy untuk menjalankan alur kerja.
* Data yang diterima dari broker MQTT seharusnya sekarang disimpan dalam tabel sensor_data di database MySQL.
tampilan node-red

Dengan konfigurasi ini, Node-Red akan secara otomatis mengambil data dari broker MQTT dan menyimpannya ke dalam database MySQL, memungkinkan pengolahan dan analisis data lebih lanjut.

[Watch the video on Google Drive](https://drive.google.com/drive/folders/1t7HDB0__3hbtFrGsi0mWfVt8j7W3ua6P?hl=id)

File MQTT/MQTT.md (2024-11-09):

## Aktifasi SSL/TLS di Broker HiveMQ Cloud
Jika kamu menggunakan HiveMQ Cloud (layanan broker MQTT yang di-host oleh HiveMQ) dan ingin mengaktifkan SSL/TLS untuk koneksi aman, berikut langkah-langkahnya:
### 1. Buat Akun dan Masuk ke HiveMQ Cloud
   * Kunjungi situs HiveMQ Cloud.
   * Buat akun atau login jika sudah memiliki akun.
   * Setelah masuk, kamu akan diarahkan ke dashboard HiveMQ Cloud.
### 2.  Buat atau Kelola MQTT Cluster
   * Di dashboard, klik "Create Cluster" untuk membuat broker MQTT baru jika belum ada. Jika sudah ada cluster, pilih cluster yang ingin kamu konfigurasi.
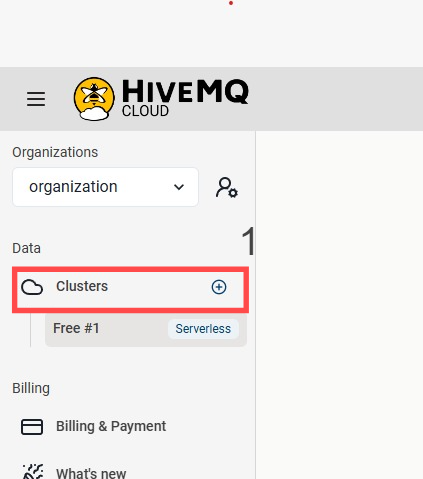
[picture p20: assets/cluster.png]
 
   
   * Setelah memilih atau membuat cluster, kamu akan masuk ke halaman detail cluster.
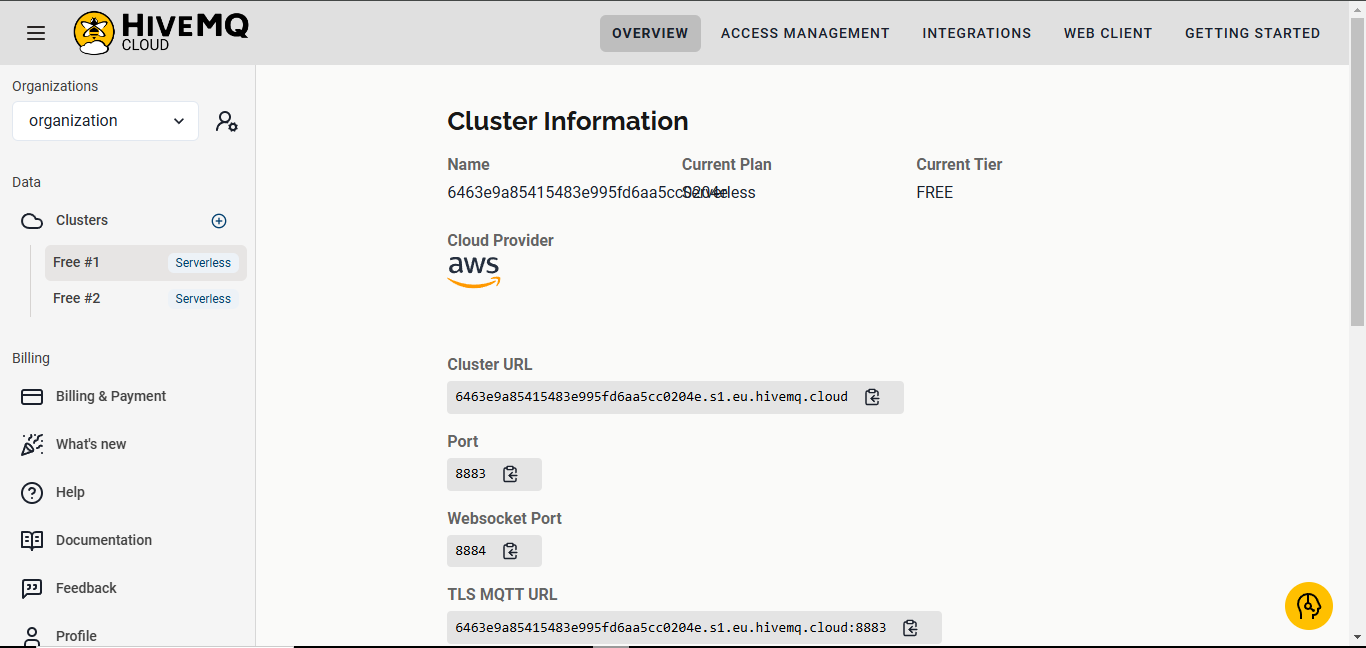
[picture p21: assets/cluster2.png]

   
### 3. Mengaktifkan SSL/TLS di HiveMQ Cloud
HiveMQ Cloud secara otomatis mengaktifkan SSL/TLS untuk koneksi aman. Kamu tidak perlu secara manual membuat atau mengunggah sertifikat, karena HiveMQ Cloud menggunakan sertifikat yang diterbitkan oleh Let's Encrypt atau penyedia sertifikat lainnya untuk mengamankan koneksi.
1. Port TLS: HiveMQ Cloud biasanya menyediakan dua port:
   * Port MQTT tanpa TLS (1883).
   * Port MQTT dengan TLS (8883).
Kamu hanya perlu memastikan bahwa klien MQTT yang kamu gunakan terhubung ke port 8883 untuk koneksi aman menggunakan SSL/TLS.

### 4. Navigasi ke Pengaturan Otentikasi
1. Pada halaman detail cluster, pilih menu "Access Management" atau "Authentication" di bagian navigasi atas.
2. Di halaman Authentication, kamu akan menemukan opsi untuk mengatur otentikasi username dan password.
   
### 5. Menambahkan Username dan Password
1. Di halaman Authentication, akan ada opsi untuk "Add User" atau "Create new credentials".
2. Klik "Add User".
  * Username: Masukkan username untuk klien yang akan menghubungkan ke broker MQTT.
  * Password: Masukkan password untuk username tersebut. Pastikan menggunakan password yang kuat untuk keamanan.
Setelah mengisi username dan password, klik "Save" atau "Add" untuk menyimpan kredensial tersebut.
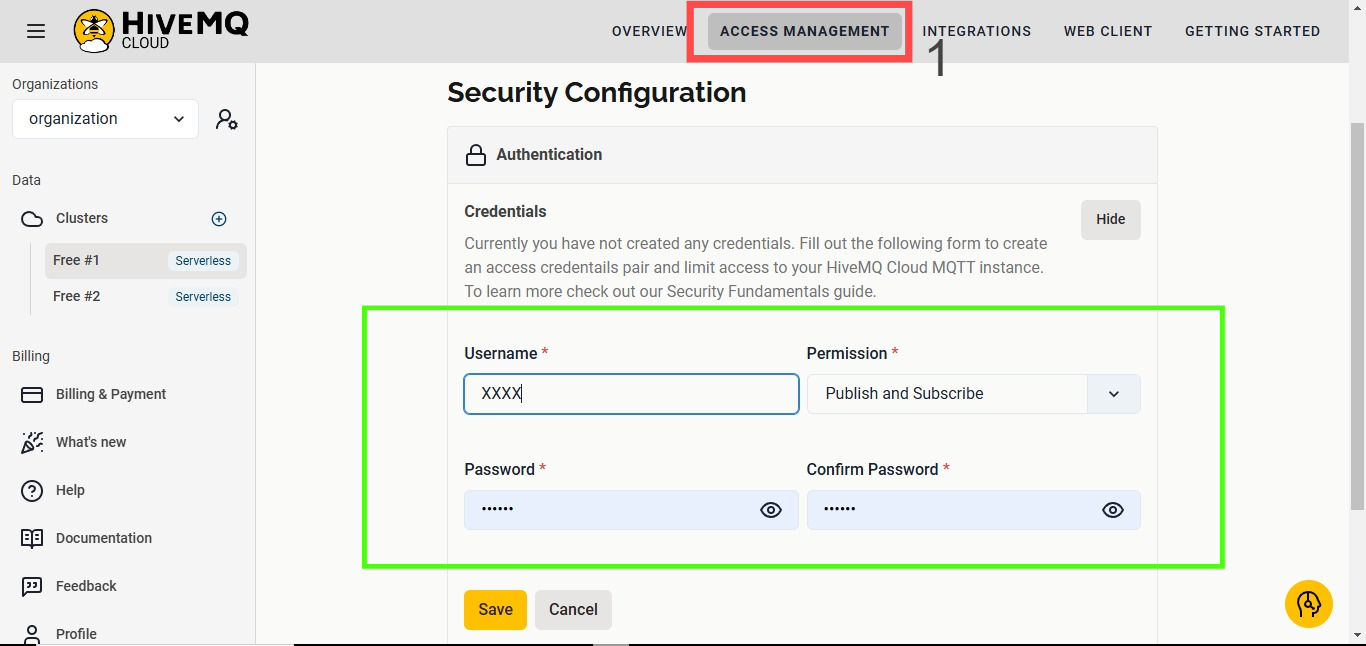
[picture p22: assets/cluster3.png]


### 6. Uji Koneksi Dengan Dengan MQTT.Cool
1. Buka Situs Test Client
   Kunjungi https://testclient-cloud.mqtt.cool/ menggunakan browser.

2. Masukkan Informasi Broker MQTT
   Setelah halaman terbuka, isi informasi koneksi broker yang relevan di antarmuka web:
   
   * Broker Address: Masukkan hostname atau alamat IP dari broker HiveMQ Cloud kamu. Misalnya, `your_hivemq_cluster_host`.
   * Port: Gunakan 8883, yang merupakan port standar untuk koneksi MQTT over TLS/SSL.
   * Client ID: Buat Client ID unik. Misalnya, `TestClient-12345`.
   * Username dan Password: Jika HiveMQ mengharuskan autentikasi, masukkan username dan password yang telah dikonfigurasi.
     
Aktifkan opsi untuk SSL/TLS dengan mencentang atau memilih opsi yang sesuai (biasanya berupa checkbox atau pilihan yang diberi label Enable SSL atau Use TLS). Ini memastikan bahwa koneksi ke broker HiveMQ menggunakan enkripsi.

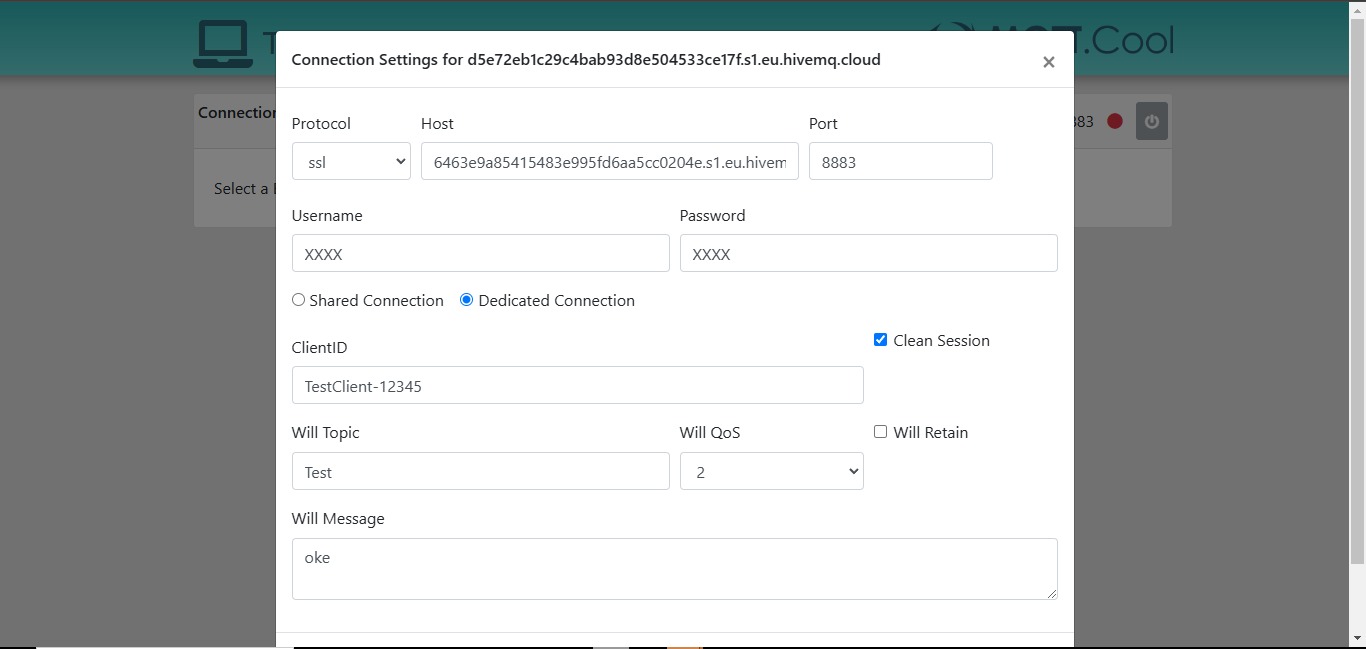
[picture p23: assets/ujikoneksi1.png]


3. Connection Settings
   
Pada navigasi Web client isi username dan password sesuai dengan Credential yang sudah dibuat pada autentification. Buatlah topik yang misalnya`Test` kemudian subcribe dan ubah Qos menjadi 2. 

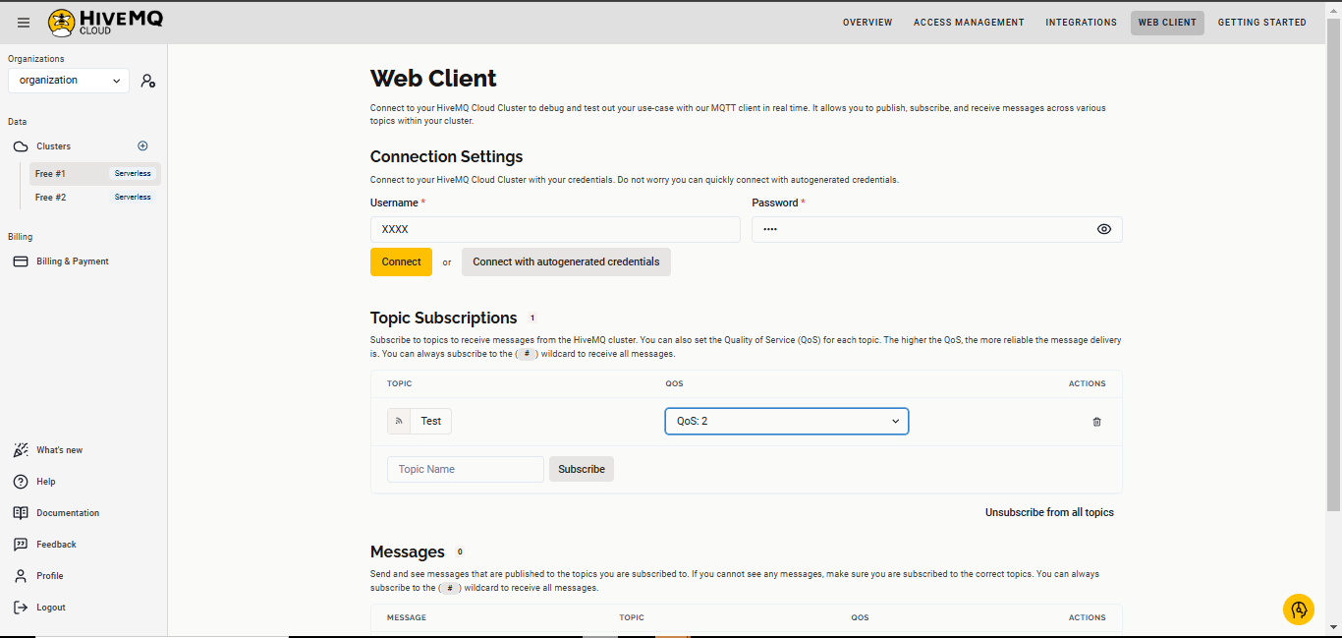
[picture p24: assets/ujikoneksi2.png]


setelah itu klik tombol connect untuk mengaktifkan koneksi broker.

4. Connect to Broker

Klik Connect atau tombol sejenis untuk mencoba terhubung ke broker HiveMQ. Jika semua konfigurasi sudah benar, klien testclient-cloud.mqtt.cool akan berhasil terhubung ke broker melalui TLS/SSL, dan status akan menunjukkan bahwa kamu terhubung.

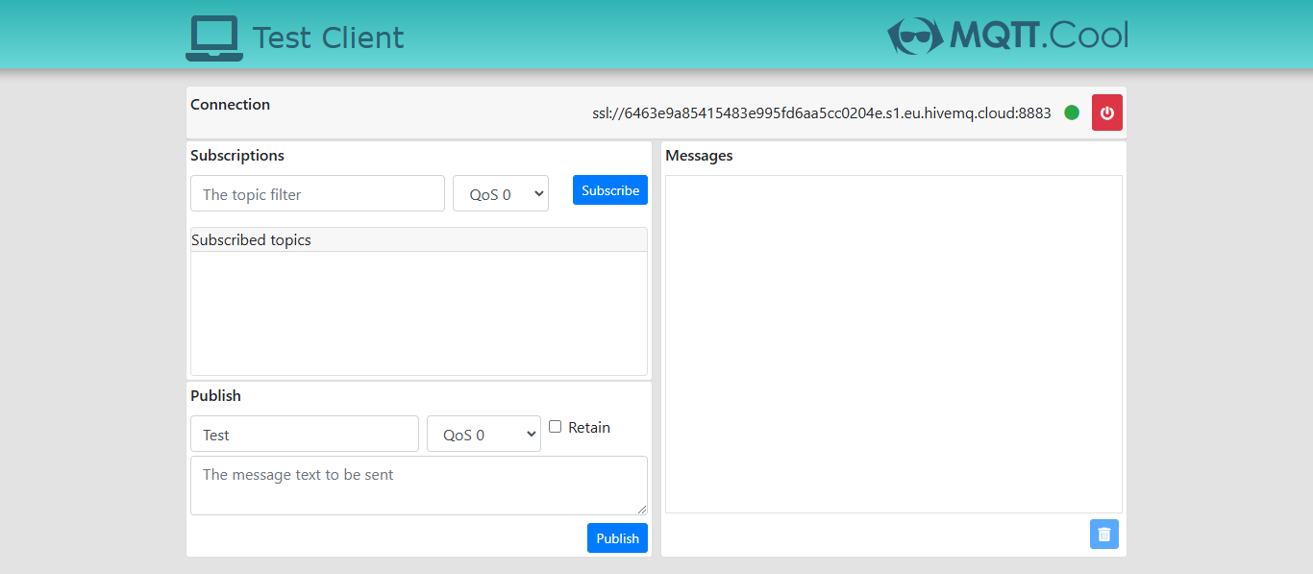
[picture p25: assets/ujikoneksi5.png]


### 7. Uji Pengiriman dan Penerimaan Pesan
Setelah koneksi berhasil:
   * Gunakan bagian Publish untuk mengirim pesan ke topik tertentu. Masukkan nama topik dan payload pesan, lalu klik Publish.
   * Untuk menerima pesan, gunakan bagian Subscribe untuk berlangganan ke topik tertentu. Masukkan nama topik dan klik Subscribe. Kamu akan menerima pesan apa pun yang dipublikasikan ke topik tersebut oleh klien lain atau oleh klien ini sendiri.
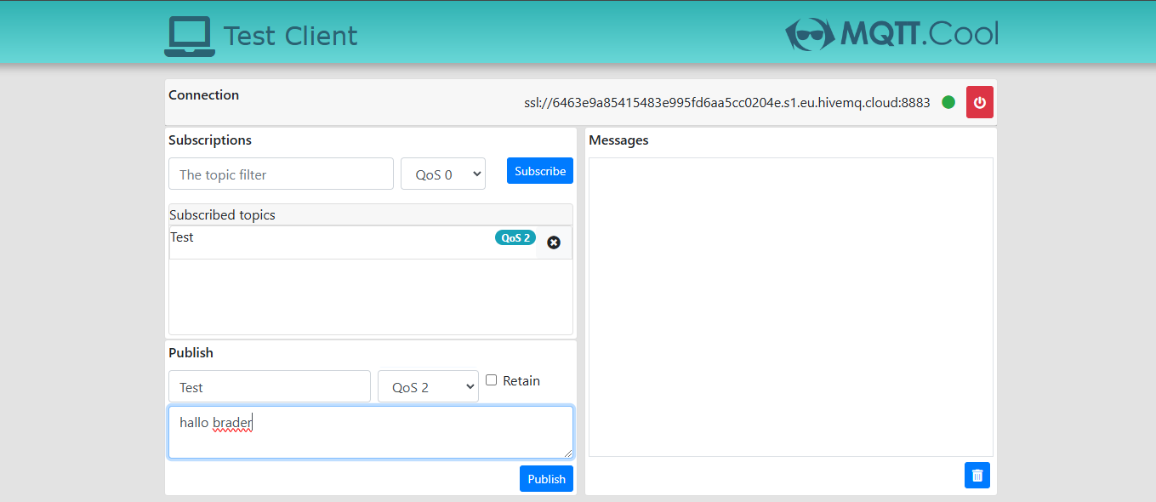
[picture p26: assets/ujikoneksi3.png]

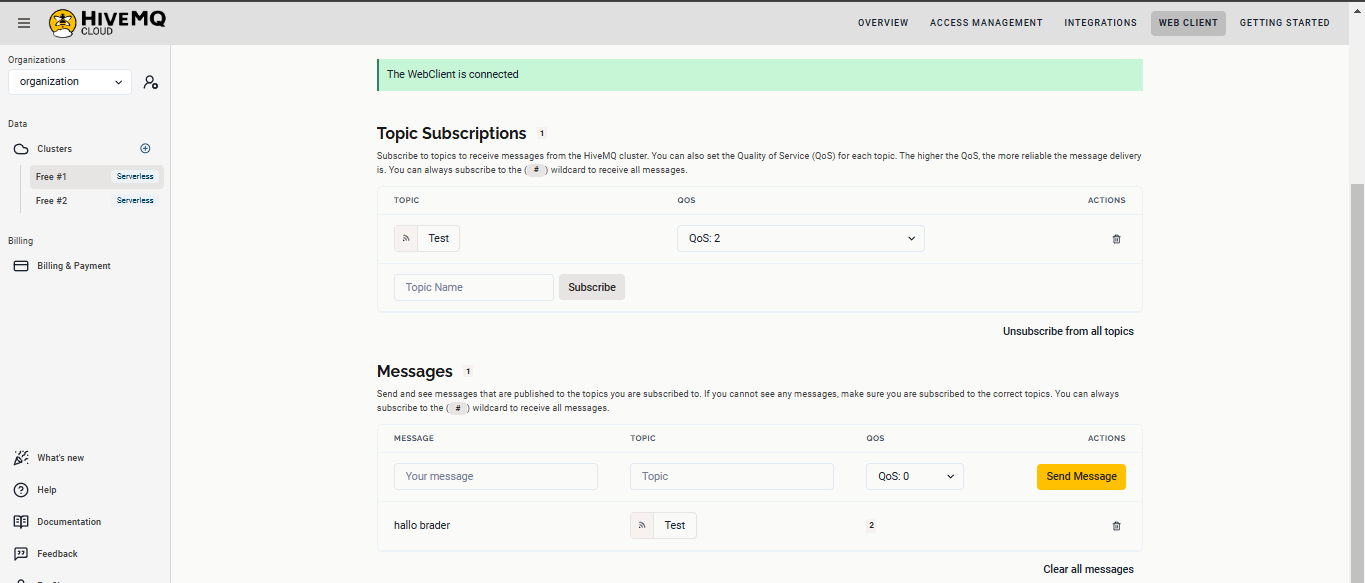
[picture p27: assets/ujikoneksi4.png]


### 8. Mengelola Username dan Password
* Kamu dapat kembali ke halaman Security/Authentication kapan saja untuk menambahkan, mengedit, atau menghapus username dan password.
* Ini berguna jika kamu ingin memberikan akses kepada lebih banyak klien atau ingin mengganti kredensial yang ada untuk meningkatkan keamanan.

Dengan pengaturan ini, broker HiveMQ Cloud kamu sudah aman dengan autentikasi berbasis username dan password, dan setiap klien yang mencoba mengakses harus memberikan kredensial yang valid.

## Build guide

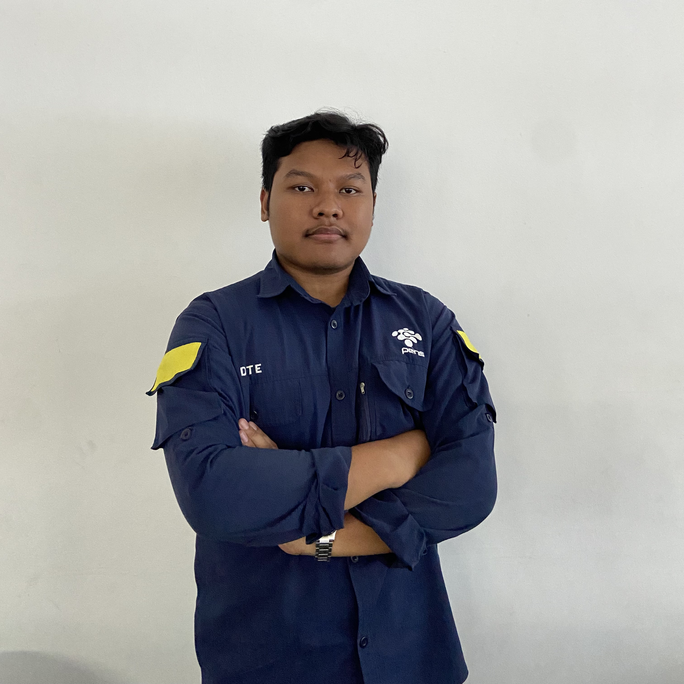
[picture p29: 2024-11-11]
Interface UI/UX/build/assets/img/fadlan.jpg

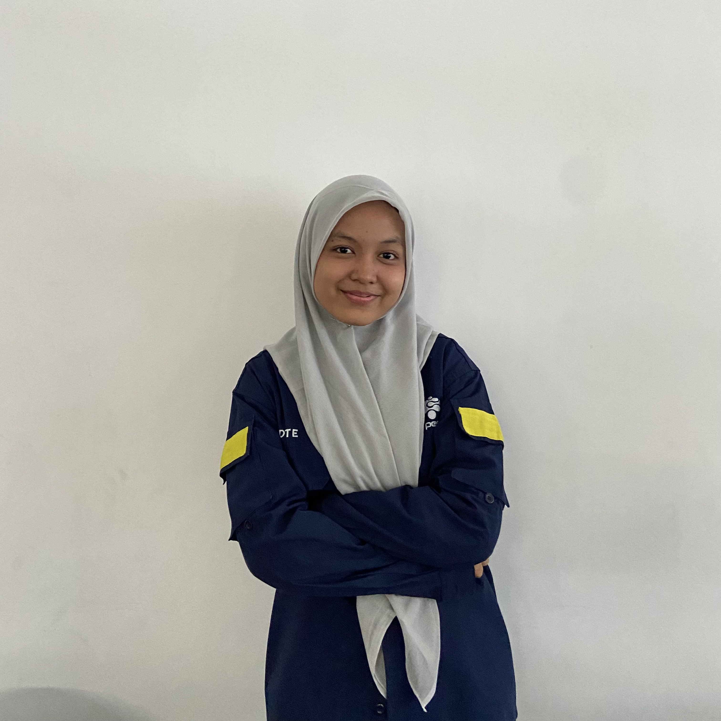
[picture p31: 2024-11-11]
Interface UI/UX/build/assets/img/rizka.jpg

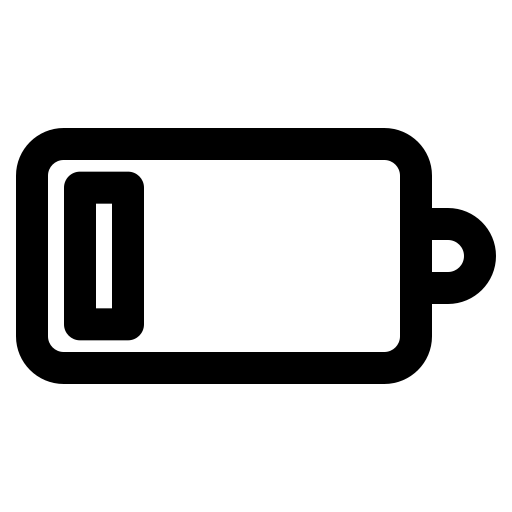
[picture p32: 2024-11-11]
Interface UI/UX/build/assets/img/LOWBAT.png

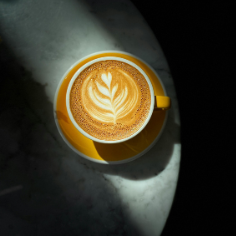
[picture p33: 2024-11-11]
Interface UI/UX/build/assets/img/6.png

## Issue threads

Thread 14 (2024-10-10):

pembuatan progam pengiriman data dari ESP32 ke broker mosquitto

faqimuh, 2024-10-10:

Closed 2024-10-13.

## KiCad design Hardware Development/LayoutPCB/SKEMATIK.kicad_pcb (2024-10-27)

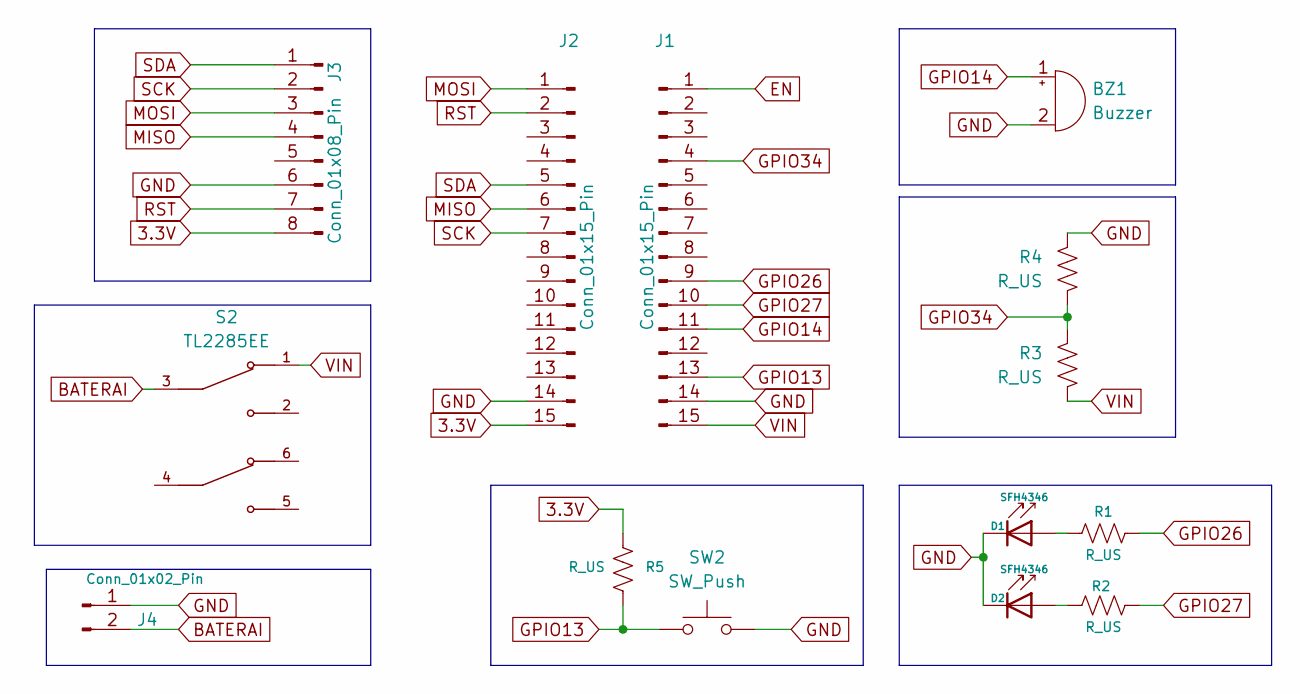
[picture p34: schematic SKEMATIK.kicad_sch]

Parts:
BZ1: Buzzer; PUIAudio_SMT_0825_S_4_R
D1, D2: SFH4346; LED_D3.0mm_IRBlack
J1, J2: Conn_01x15_Pin; PinHeader_1x15_P2.54mm_Vertical
J3: Conn_01x08_Pin; PinHeader_1x08_P2.54mm_Vertical
J4: Conn_01x02_Pin; JST_EH_B2B-EH-A_1x02_P2.50mm_Vertical
R1, R2, R3, R4, R5: R_US; R_1206_3216Metric
S2: TL2285EE; SW_TL2285EE; PARTREV B
SW2: SW_Push; SW_PUSH_6mm

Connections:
3.3V: J2.15, J3.8, R5.1
BATERAI: J4.2, S2.3
EN: J1.1
GND: BZ1.2 (-), D1.1 (K), D2.1 (K), J1.14, J2.14, J3.6, J4.1, R4.1, SW2.2
GPIO13: J1.13, R5.2, SW2.1
GPIO14: BZ1.1 (+), J1.11
GPIO26: J1.9, R1.2
GPIO27: J1.10, R2.2
GPIO34: J1.4, R3.1, R4.2
MISO: J2.6, J3.4
MOSI: J2.1, J3.3
unnamed: D1.2 (A), R1.1
unnamed: D2.2 (A), R2.1
RST: J2.2, J3.7
SCK: J2.7, J3.2
SDA: J2.5, J3.1
VIN: J1.15, R3.2, S2.1

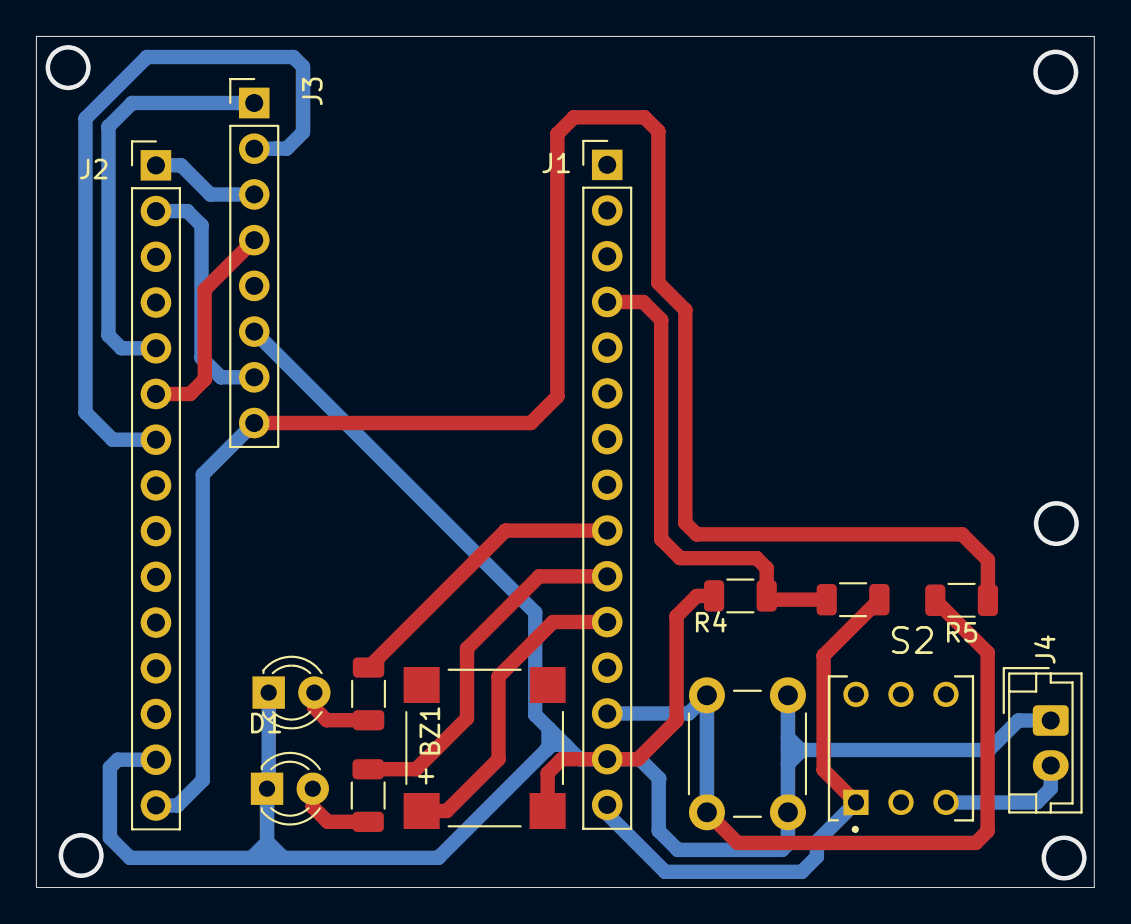
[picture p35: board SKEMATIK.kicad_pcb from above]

Board: 2 copper layers, 58.8 x 47.3 mm, 14 parts (0 on the bottom side), 16 nets.

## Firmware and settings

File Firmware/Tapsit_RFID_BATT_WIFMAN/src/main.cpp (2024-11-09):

#include <WiFi.h>
#include <WiFiManager.h>  // Menggunakan WiFiManager untuk pengaturan WiFi
#include <PubSubClient.h>
#include "esp32-hal-timer.h"
#include <Preferences.h>
#include <SPI.h>
#include <MFRC522.h>

Preferences preferences;

#define TRIGGER_PIN 13
#define level 34
#define RST_PIN 22      // RST Pin
#define SS_PIN  21       // SDA Pin (CS)
#define red_led 26
#define green_led 27
#define buzzer  14


MFRC522 mfrc522(SS_PIN, RST_PIN);
bool wm_nonblocking = false; // change to true to use non blocking
WiFiManager wm; // global wm instance
WiFiManagerParameter custom_field; // global param ( for non blocking w params )

// Update these with values suitable for your network.

//const char* mqtt_server = "d5e72eb1c29c4bab93d8e504533ce17f.s1.eu.hivemq.cloud";
const char* mqtt_server = "broker.mqtt.cool";
const int mqttPort = 1883; // Port default untuk MQTT
const char* mqttUser = "TapSit";
const char* mqttPassword = "TapSit";

WiFiClient espClient;
PubSubClient client(espClient);

unsigned long lastMsg = 0;
#define MSG_BUFFER_SIZE (50)
char msg[MSG_BUFFER_SIZE];
String meja;

int batt;

hw_timer_t *timer = NULL;  // Timer untuk interrupt
volatile bool timerFlag = false;
bool res;
// Fungsi interrupt untuk pengambilan sampel
void IRAM_ATTR onTimer() {
  timerFlag = true; 
  batt=(int)((analogRead(level)/4095.0)*100); 
}

// Fungsi reconnect untuk koneksi ke MQTT broker
void reconnect() {
  while (!client.connected()) {
    Serial.print("Attempting MQTT connection...");
    String clientId = "ESP32Client-";
    clientId += String(random(0xffff), HEX);
    if (client.connect(clientId.c_str(), mqttUser, mqttPassword)) {
      Serial.println("connected");
    } else {
      Serial.print("failed, rc=");
      Serial.print(client.state());
      Serial.println(" try again in 5 seconds");
      delay(5000);
    }
  }
}
void saveParamCallback();
void setup() {
  Serial.begin(115200);
  
  pinMode(level,INPUT);
  pinMode(TRIGGER_PIN, INPUT);
  pinMode(red_led,OUTPUT);
  pinMode(green_led,OUTPUT);

  ledcSetup(0, 2000, 8);  // Kanal 0, frekuensi awal 2000 Hz, resolusi 8-bit
  ledcAttachPin(buzzer, 0);


  SPI.begin();           // Memulai SPI bus
  mfrc522.PCD_Init();    // Inisialisasi RFID reader
  
  WiFi.mode(WIFI_STA); // explicitly set mode, esp defaults to STA+AP  
  
  Serial.setDebugOutput(true);  
  delay(3000);
  Serial.println("\n Starting");

  
  preferences.begin("identitas", true);
  meja = preferences.getString("deviceID", "NULL");
  preferences.end();
   if (meja == "0") {
        Serial.println("No saved username found. Using default.");
    } else {
        Serial.print("Saved Username: ");
        Serial.println(meja);
    }
   //wm.resetSettings(); // wipe settings

  if(wm_nonblocking) wm.setConfigPortalBlocking(false);

  // Menggunakan HTML kustom
  const char *customHtml = "<label for='myFieldId'>INPUT NOMOR MEJA</label><input type='int' name='myFieldId' placeholder='Chair number at integer value'>";
  WiFiManagerParameter customField3(customHtml); // Menggunakan HTML kustom

  // Menambahkan parameter ke WiFiManager
  wm.addParameter(&customField3);

  
  wm.setSaveParamsCallback(saveParamCallback);

  // custom menu via array or vector
   std::vector<const char *> menu = {"wifi","info","param","sep","restart","exit"};
  wm.setMenu(menu);

  // set dark theme
  wm.setClass("invert");


  // wm.setConnectTimeout(20); // how long to try to connect for before continuing
  wm.setConfigPortalTimeout(30); // auto close configportal after n seconds
  
  // res = wm.autoConnect(); // auto generated AP name from chipid
   res = wm.autoConnect("TAPSIT"); // anonymous ap
  //res = wm.autoConnect("AutoConnectAP","password"); // password protected ap

  if(!res) {
    Serial.println("Failed to connect or hit timeout");
    // ESP.restart();
  } 
  else {
    //if you get here you have connected to the WiFi    
    Serial.println("connected...yeey :)");
  }
 
  client.setServer(mqtt_server, mqttPort);

  // Inisialisasi timer dengan timer 0, divider 80, dan count up
  timer = timerBegin(0, 80, true);  // Timer 0, divider 80 (prescaler 80 MHz), hitung ke atas
  
  // Hubungkan interrupt ke fungsi onTimer, dengan rising edge (true)
  timerAttachInterrupt(timer, &onTimer, true);
  
  // Atur alarm ke 10.000.000 mikrodetik (10 detik), dengan autoreload
  timerAlarmWrite(timer, 10000000, true);  // 10 juta microseconds, autoreload diaktifkan
  
  // Aktifkan alarm
  timerAlarmEnable(timer);
}
void checkButton(){
  // check for button press
  if ( digitalRead(TRIGGER_PIN) == LOW ) {
    // poor mans debounce/press-hold, code not ideal for production
    delay(50);
    if( digitalRead(TRIGGER_PIN) == LOW ){
      Serial.println("Button Pressed");
      // still holding button for 3000 ms, reset settings, code not ideaa for production
      delay(3000); // reset delay hold
      if( digitalRead(TRIGGER_PIN) == LOW ){
        Serial.println("Button Held");
        Serial.println("Erasing Config, restarting");
        wm.resetSettings();
        ESP.restart();
      }
      
      // start portal w delay
      Serial.println("Starting config portal");
      wm.setConfigPortalTimeout(120);
      
      if (!wm.startConfigPortal("TAPSIT")) {
        Serial.println("failed to connect or hit timeout");
        delay(3000);
        // ESP.restart();
      } else {
        //if you get here you have connected to the WiFi
        Serial.println("connected...yeey :)");
      }
    }
  }
}
String getParam(String name){
  //read parameter from server, for customhmtl input
  String value;
  if(wm.server->hasArg(name)) {
    value = wm.server->arg(name);
  }
  return value;
}

void saveParamCallback(){
   getParam("myFieldId");
   // Mulai Preferences di namespace "config"
    preferences.begin("identitas", false);
    
    // Simpan nilai custom parameter
    preferences.putString("deviceID", getParam("myFieldId"));
    meja = preferences.getString("deviceID", "NULL");
    // Tutup Preferences
    preferences.end();
  Serial.println("[CALLBACK] saveParamCallback fired");
  Serial.println("PARAM customfieldid = " + getParam("myFieldId"));
}
void loop() {
  
  if(wm_nonblocking) wm.process(); // avoid delays() in loop when non-blocking and other long running code  
  checkButton();
  if(res){
  if (!client.connected() ) {
    reconnect();
  }
  client.loop();
  unsigned long now = millis();
  
  if(timerFlag){
    timerFlag = false;  // Reset flag
  }
  
  //if (now - lastMsg > 2000) {
    //lastMsg = now;
    if (!mfrc522.PICC_IsNewCardPresent() || !mfrc522.PICC_ReadCardSerial()) {
      digitalWrite(green_led,HIGH);
      digitalWrite(red_led,LOW);
      return;
    }
    
    // Membaca UID kartu dan mencetaknya
    Serial.print("UID Kartu Terdeteksi: ");
    String uid = "";
    for (byte i = 0; i < mfrc522.uid.size; i++) {
      if (mfrc522.uid.uidByte[i] < 0x10) {
       // Serial.print("0");
      }
      //Serial.print(mfrc522.uid.uidByte[i], HEX);
      uid += String(mfrc522.uid.uidByte[i] < 0x10 ? "0" : "") + String(mfrc522.uid.uidByte[i], HEX);
    }

    snprintf(msg, MSG_BUFFER_SIZE, "meja:%s,rfid:%s,batt:%d,", meja, uid, batt);
    delay(1000);  // Delay untuk menunggu kartu diangkat
    mfrc522.PICC_HaltA(); // Menghentikan komunikasi dengan kartu
    
   
  
    Serial.print("Publish message: ");
    Serial.println(msg);
    client.publish("tapsit", msg);  // Kirim pesan ke broker MQTT 
    
     digitalWrite(red_led,HIGH);
    digitalWrite(green_led,LOW);
   ledcWriteTone(0, 1500); 
    delay(1500);
     ledcWriteTone(0, 0); 
  }
  }
//}

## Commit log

2024-10-08 Create prototype
2024-10-13 Penjelasan skematik dan pcb ditaruh di readmed
2024-10-20 berkas sch
    [skematik_new_terbaru.kicad_sch]
2024-10-20 desain pcb hasil revisi
    [skematik_new_19-Oct.kicad_pcb]
2024-10-23 perbarui file skematik,layout,dan tampilan 3D PCB
    [SKEMATIK.kicad_pcb, SKEMATIK.kicad_sch, skematik_new_19-Oct.kicad_pcb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]
2024-10-27 Update Readme aktifasi SSL di HiveMQ .md
2024-10-27 Update Readme aktifasi SSL di HiveMQ1
2024-11-02 saya sudah uploud di thingverse,sehingga file bisa dicetak di 3D print
